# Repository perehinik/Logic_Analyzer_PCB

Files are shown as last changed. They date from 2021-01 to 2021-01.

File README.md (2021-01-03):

# Logic_Analizer_PCB
KiCad PCB project of Logic Analyzer

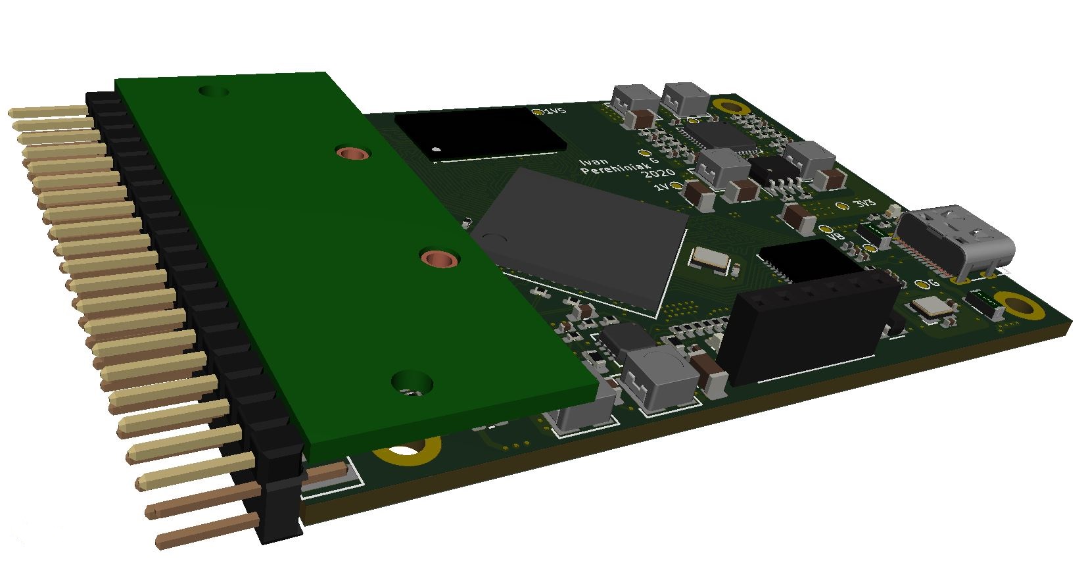
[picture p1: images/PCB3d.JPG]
  
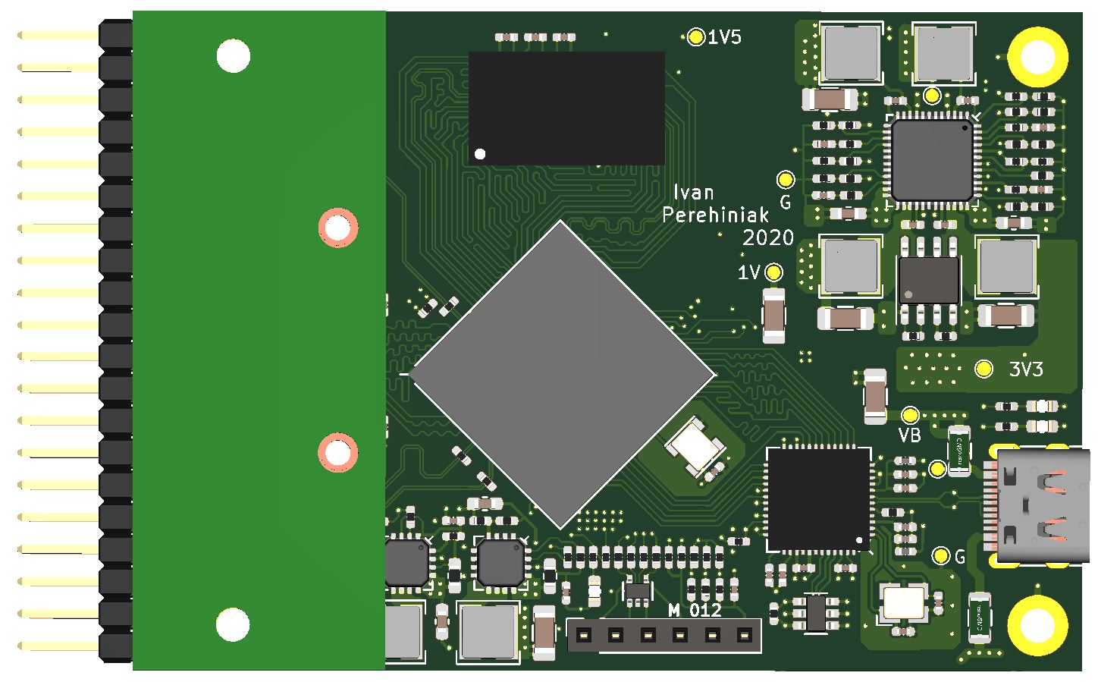
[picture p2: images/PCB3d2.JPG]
   
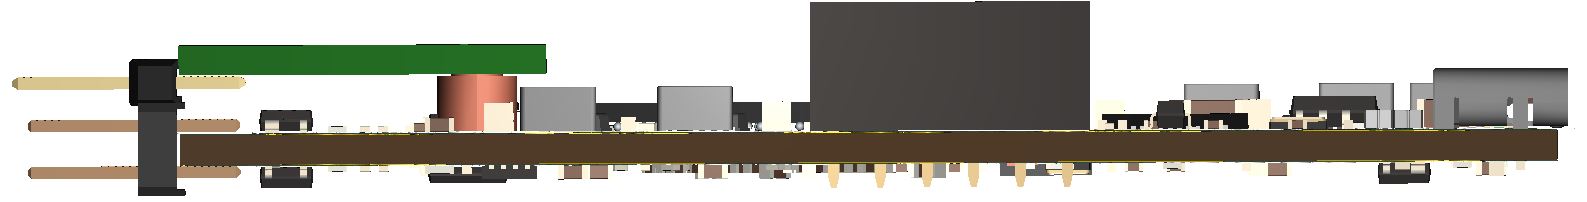
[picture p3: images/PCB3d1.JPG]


All components were soldered by hand using Zhaoxin 898DH station  
  
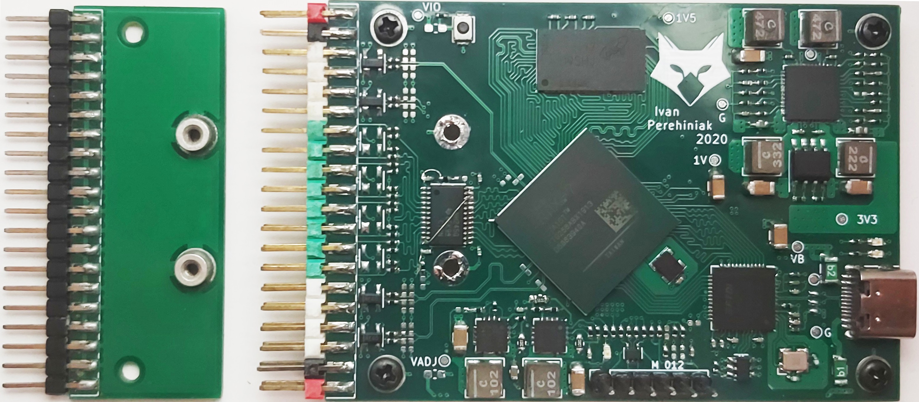
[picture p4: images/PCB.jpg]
   
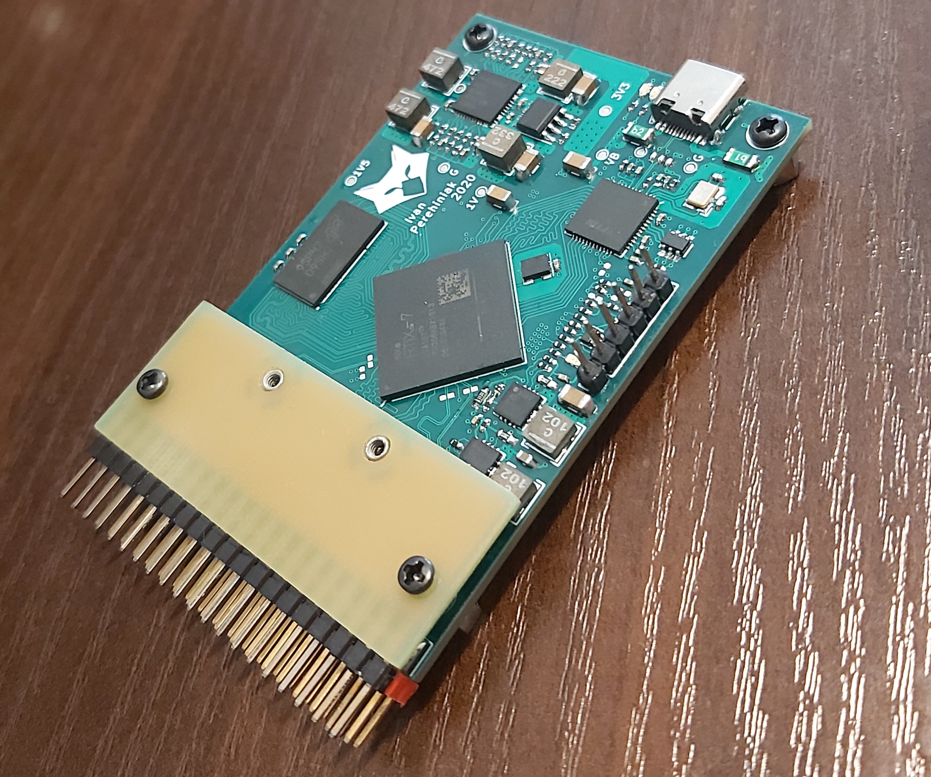
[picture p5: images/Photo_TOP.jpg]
   
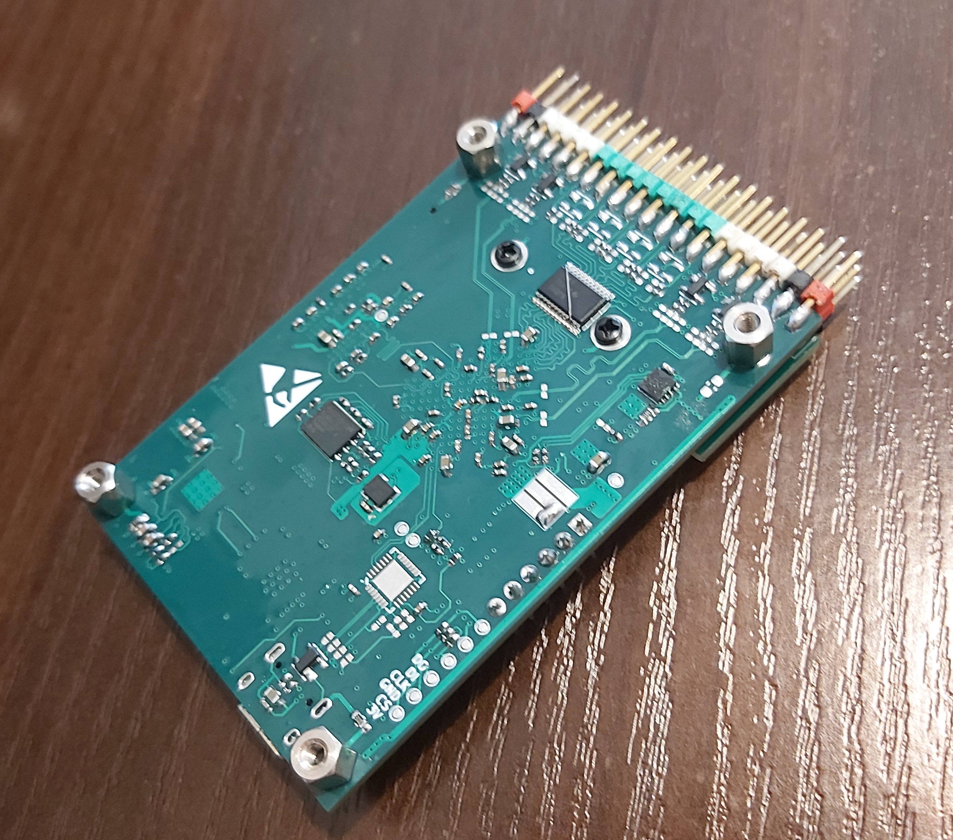
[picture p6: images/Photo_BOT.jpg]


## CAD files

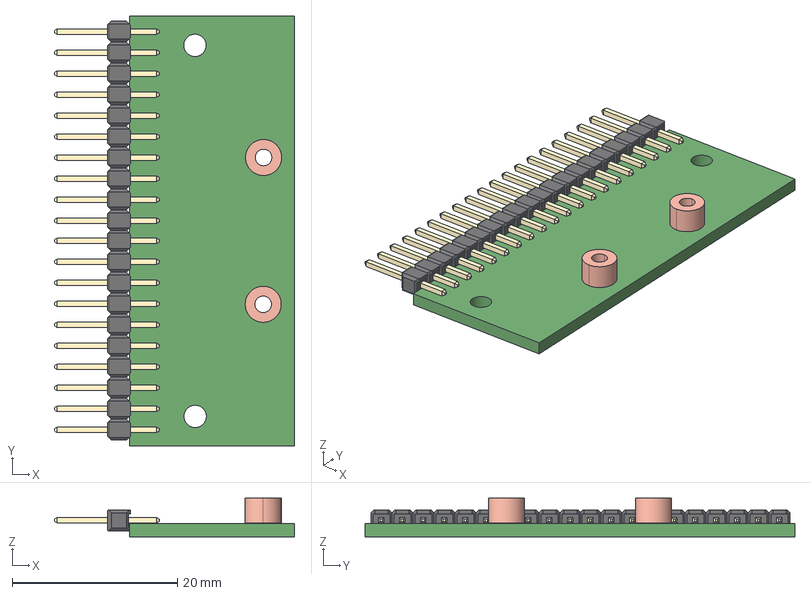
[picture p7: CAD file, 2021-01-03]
Project/GND_PCB/GND_PCB.step
29.1 x 52.0 x 4.70 mm

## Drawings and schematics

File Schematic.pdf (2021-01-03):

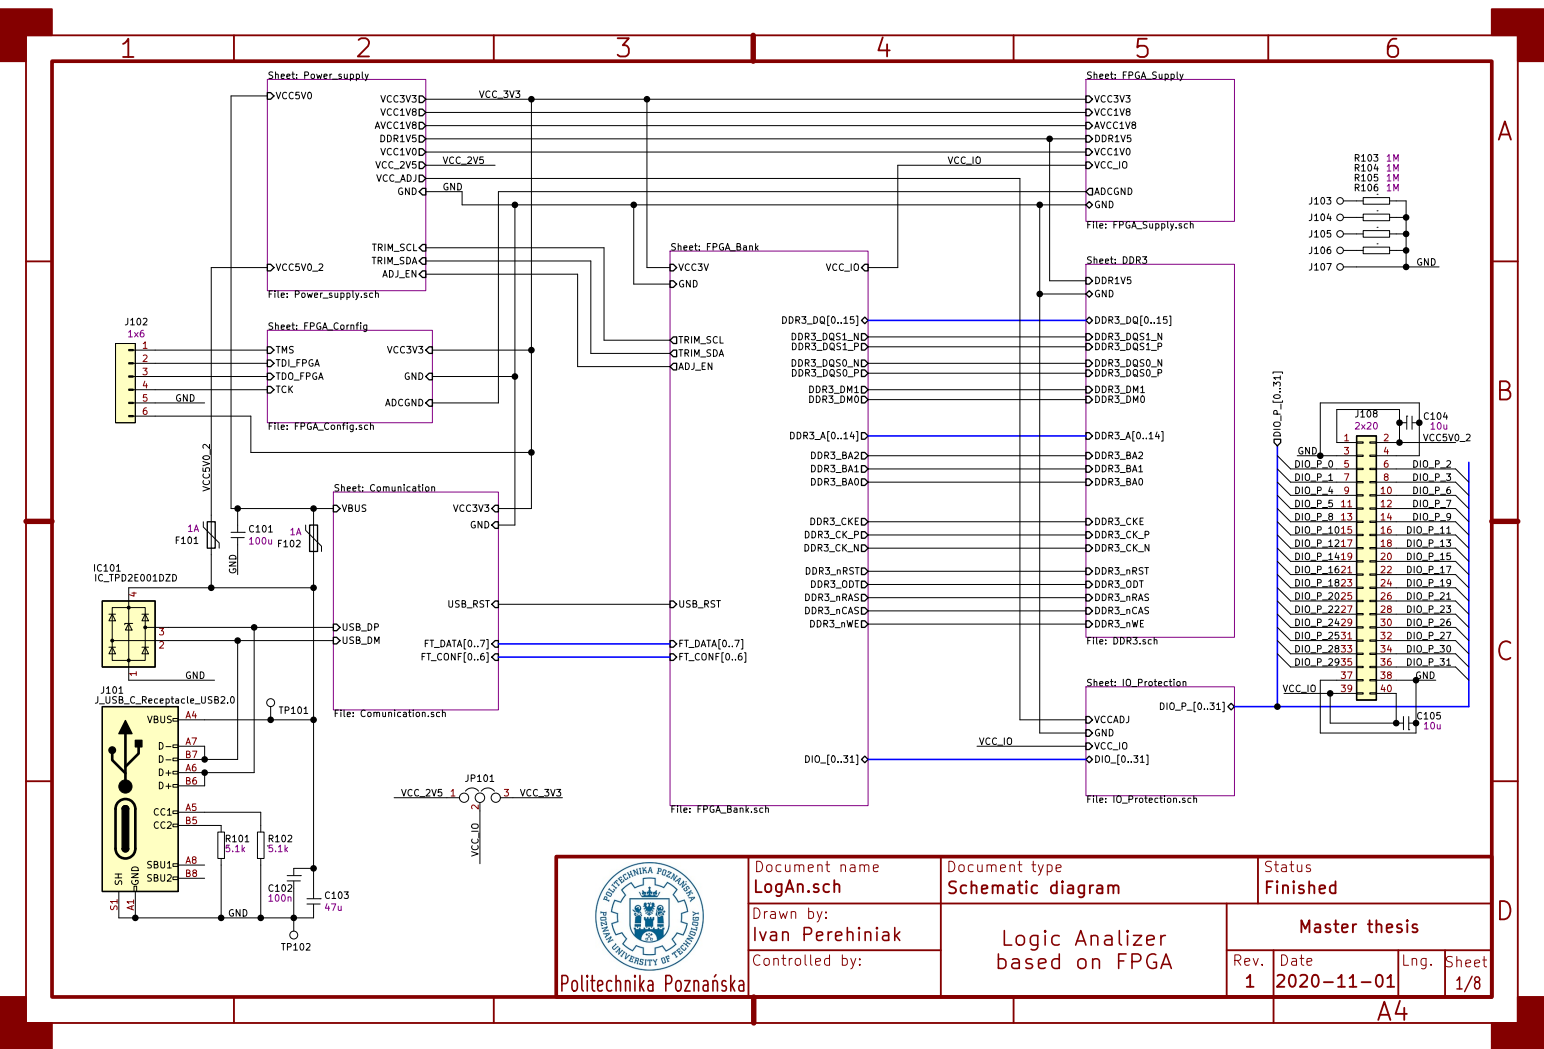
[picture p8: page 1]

Drawn by: Logic Analizer

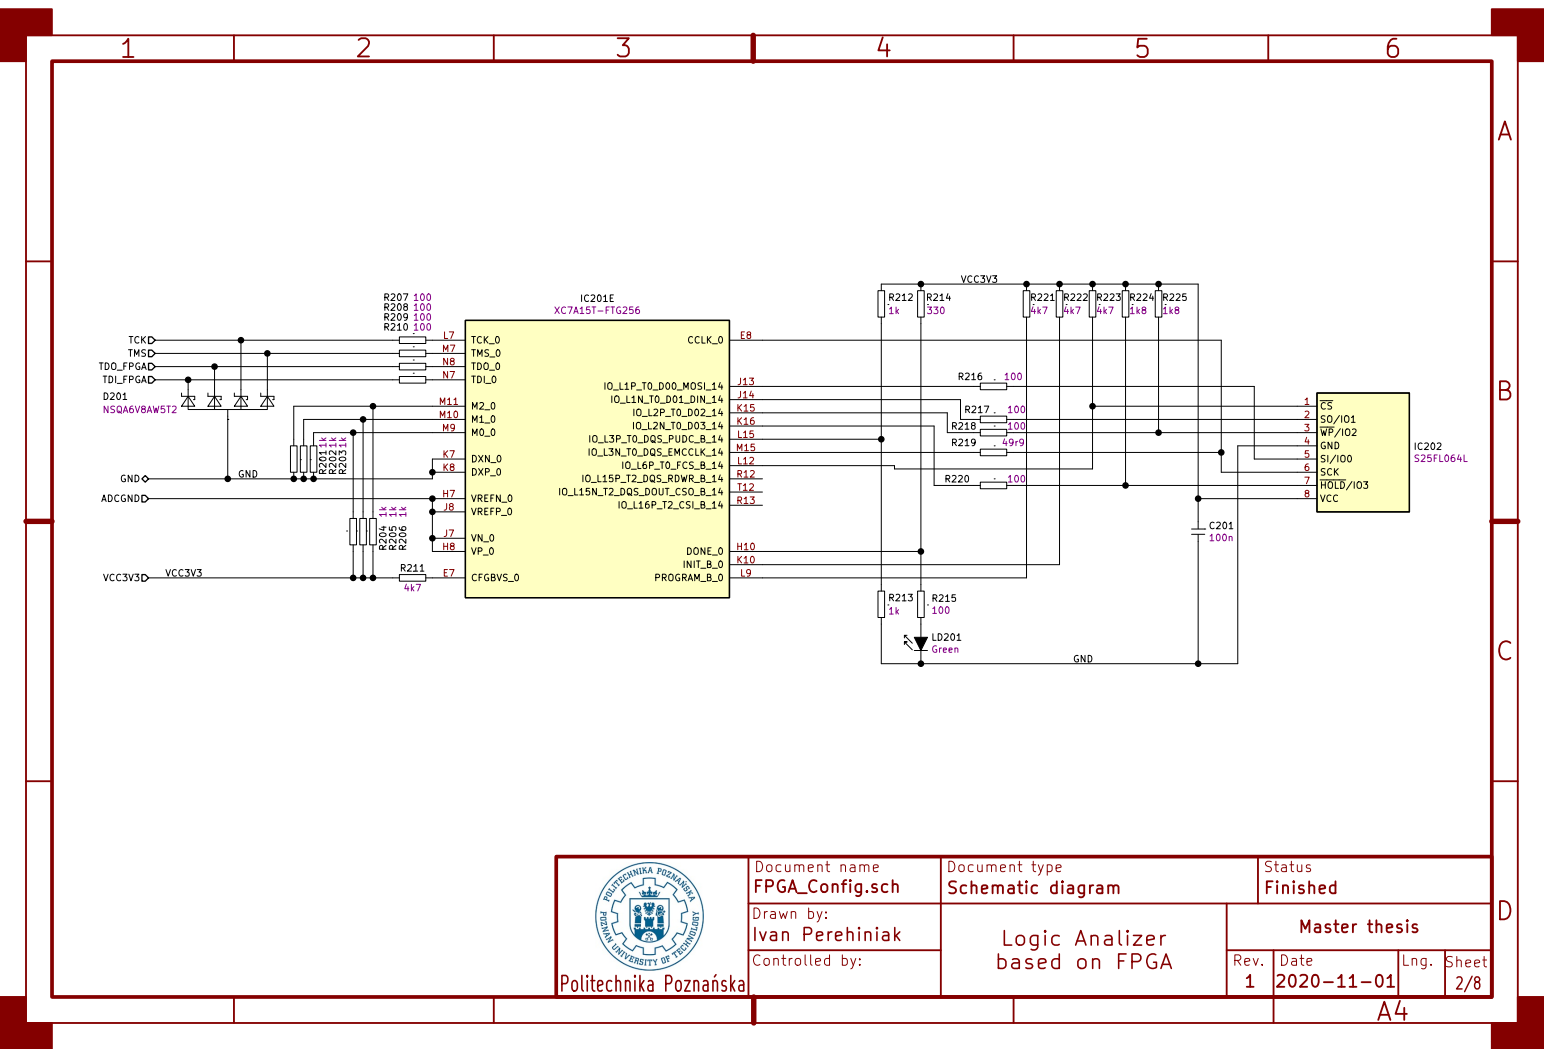
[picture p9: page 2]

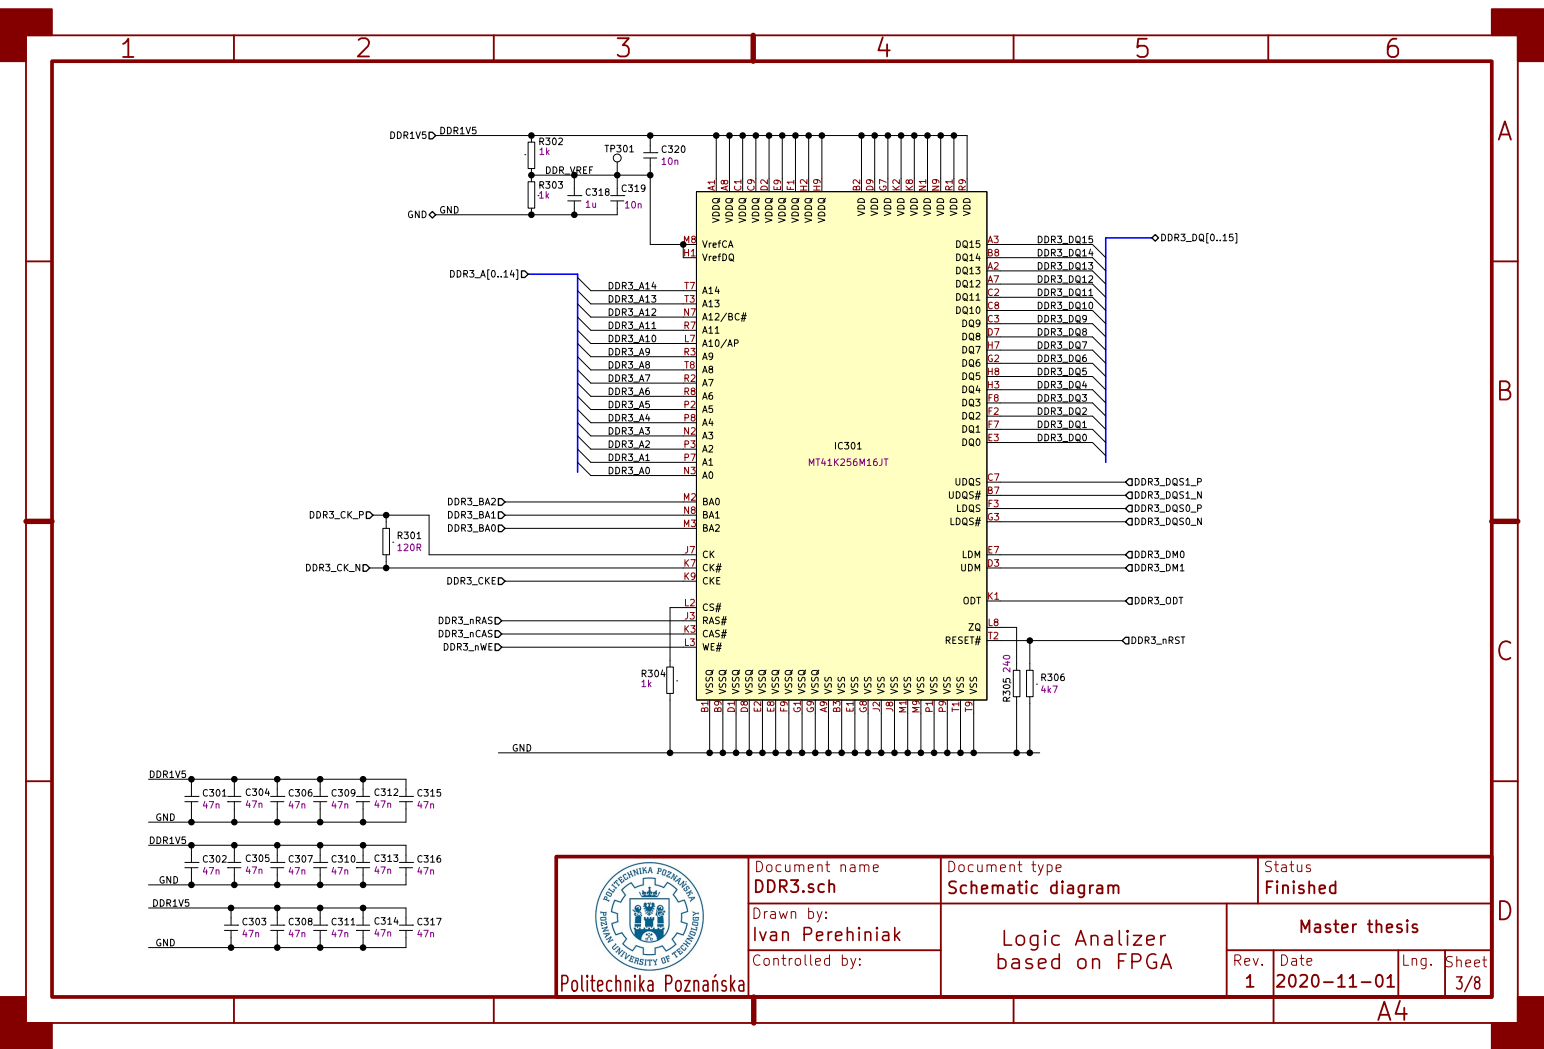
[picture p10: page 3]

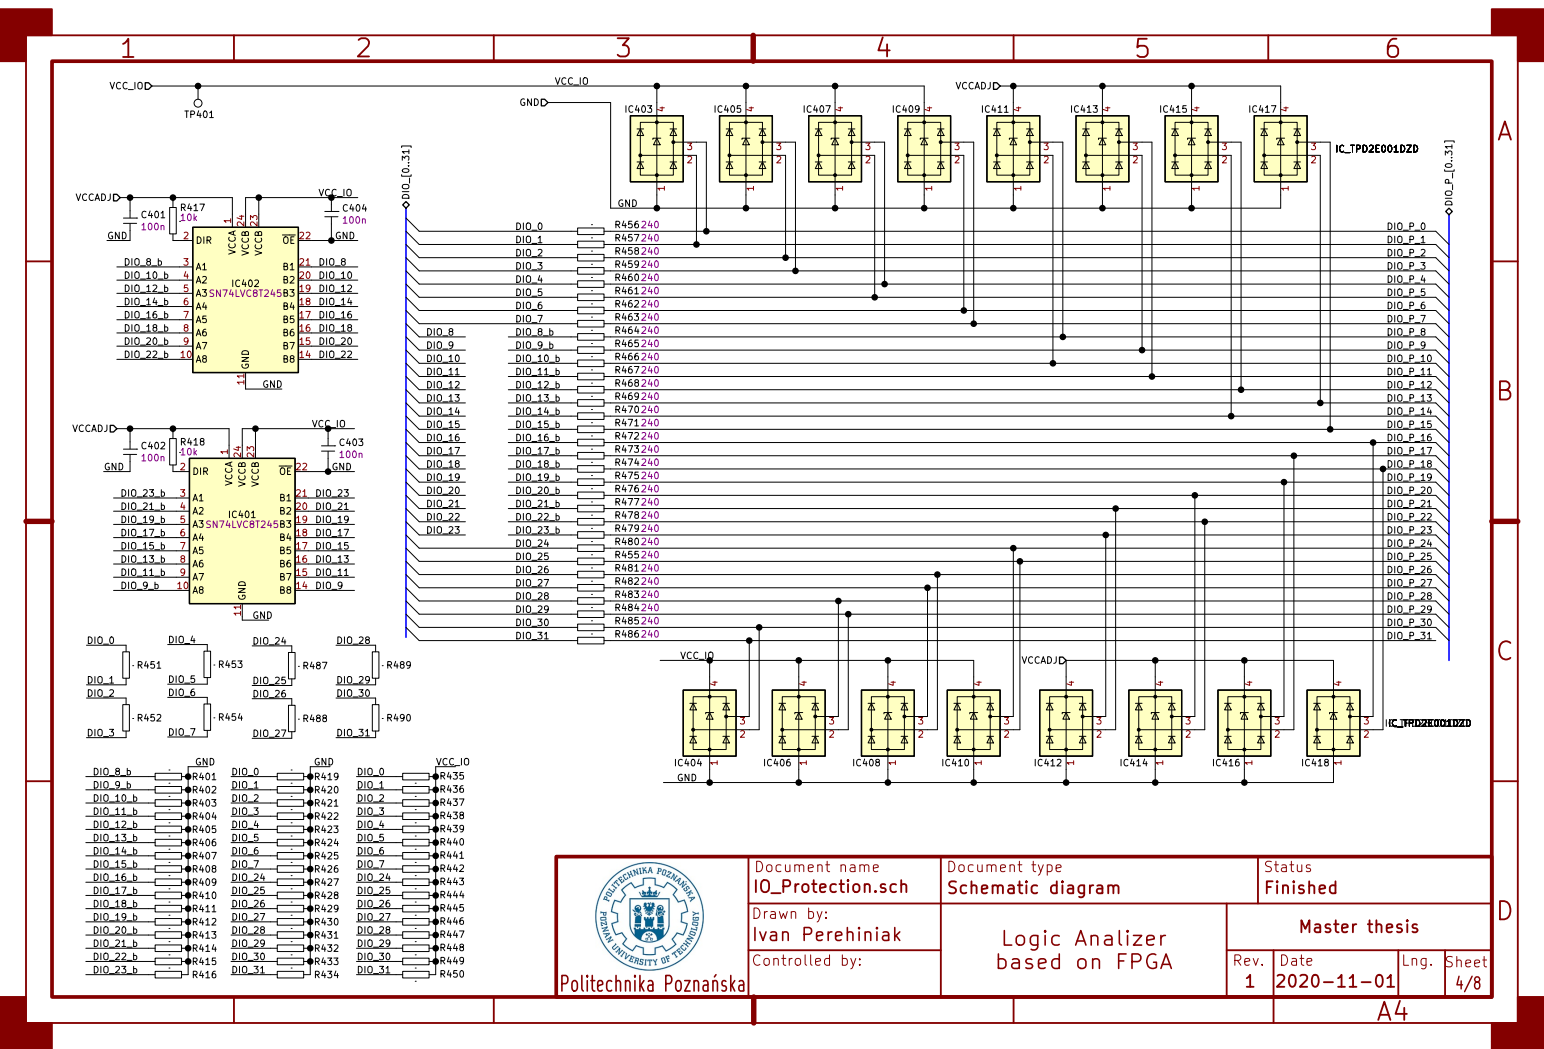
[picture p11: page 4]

1 A8 10 GND 11 B8 14 B7 15 B6 16 B5 17 B4 18 B3 19 DIR 2 B2 20 B1 21 OE 22 VCCB 23 VCCB 24 A1 3 A2 4 A3 5 A4 6 A5 7 A6 8 A7 9

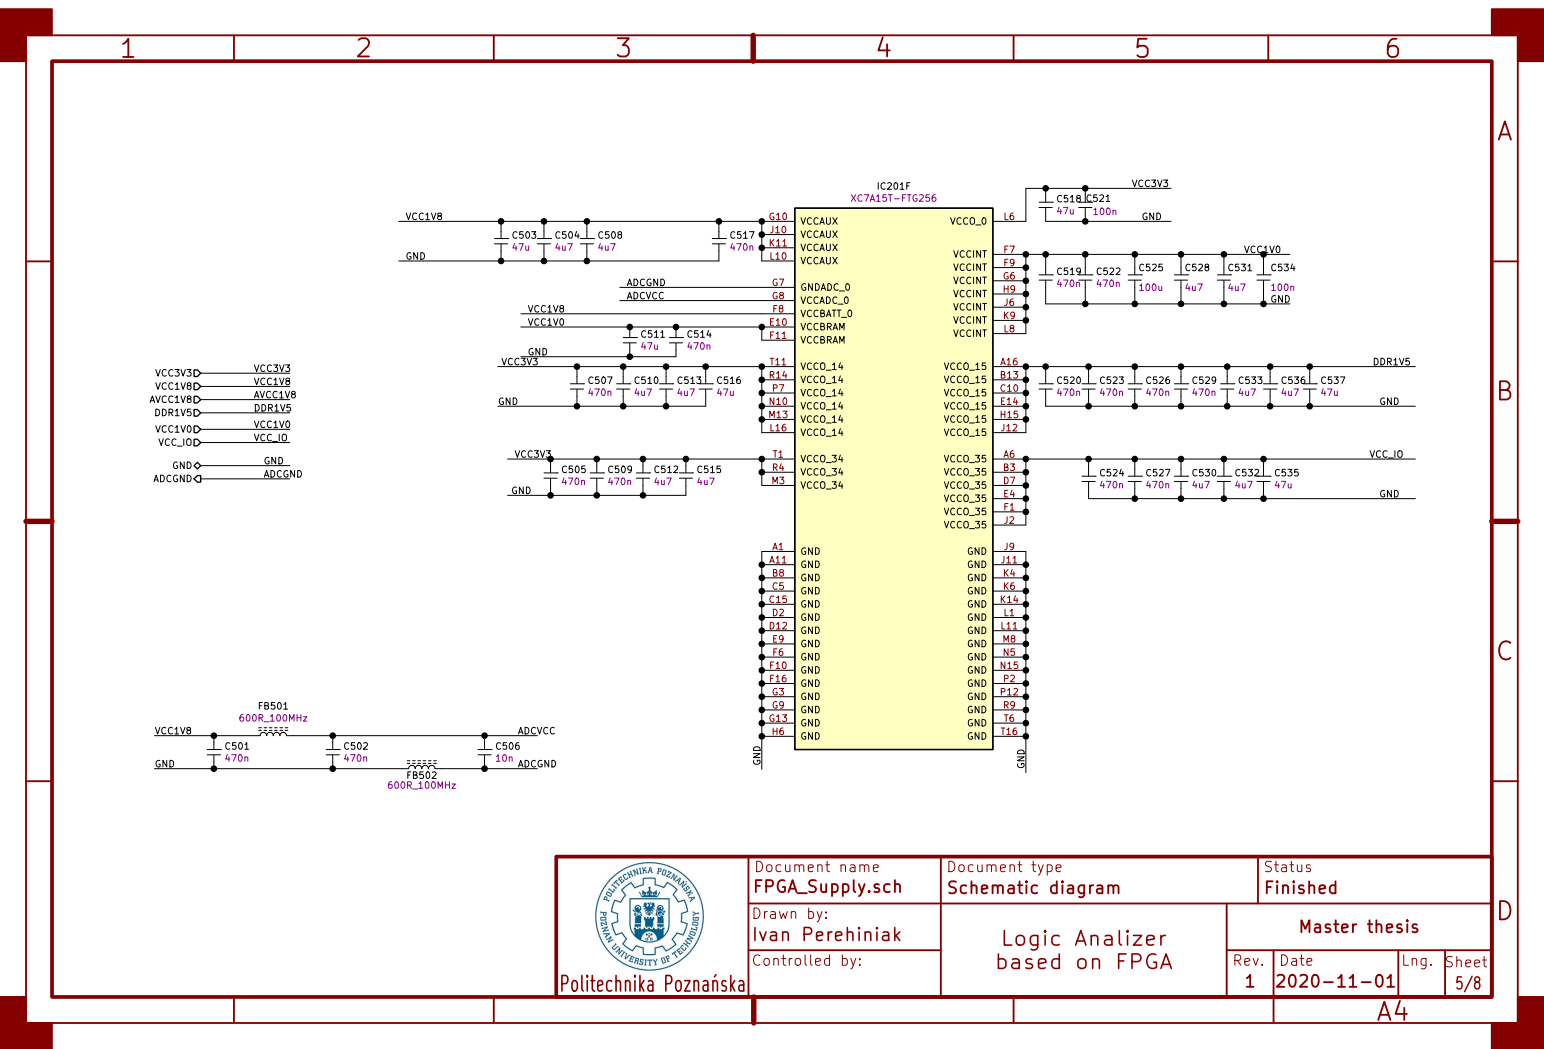
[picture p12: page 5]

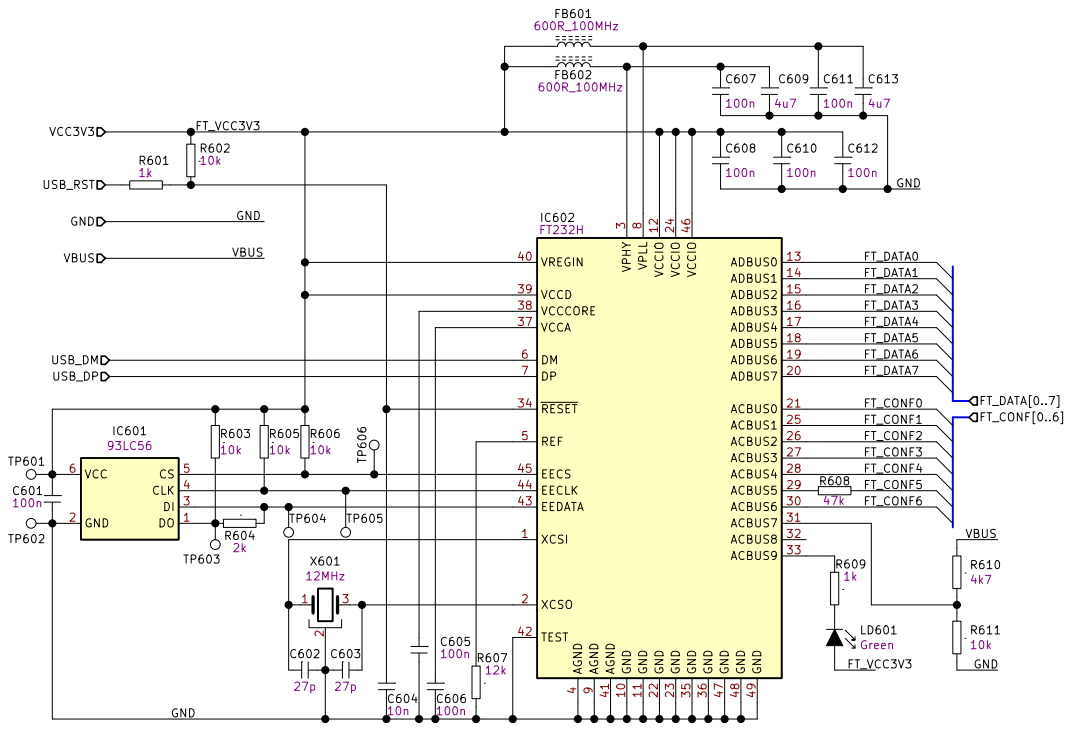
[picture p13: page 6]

4 VREGIN 40 AGND 41 TEST 42 EEDATA 43 EECLK 44 EECS 45 VCCIO 46 GND 47 GND 48 GND 49 REF 5 DM 6 DP 7 VPLL

3 ACBUS6 30 ACBUS7 31 ACBUS8 32 ACBUS9 33 RESET 34 GND 35 GND 36 VCCA 37 VCCCORE 38 VCCD 39 AGND

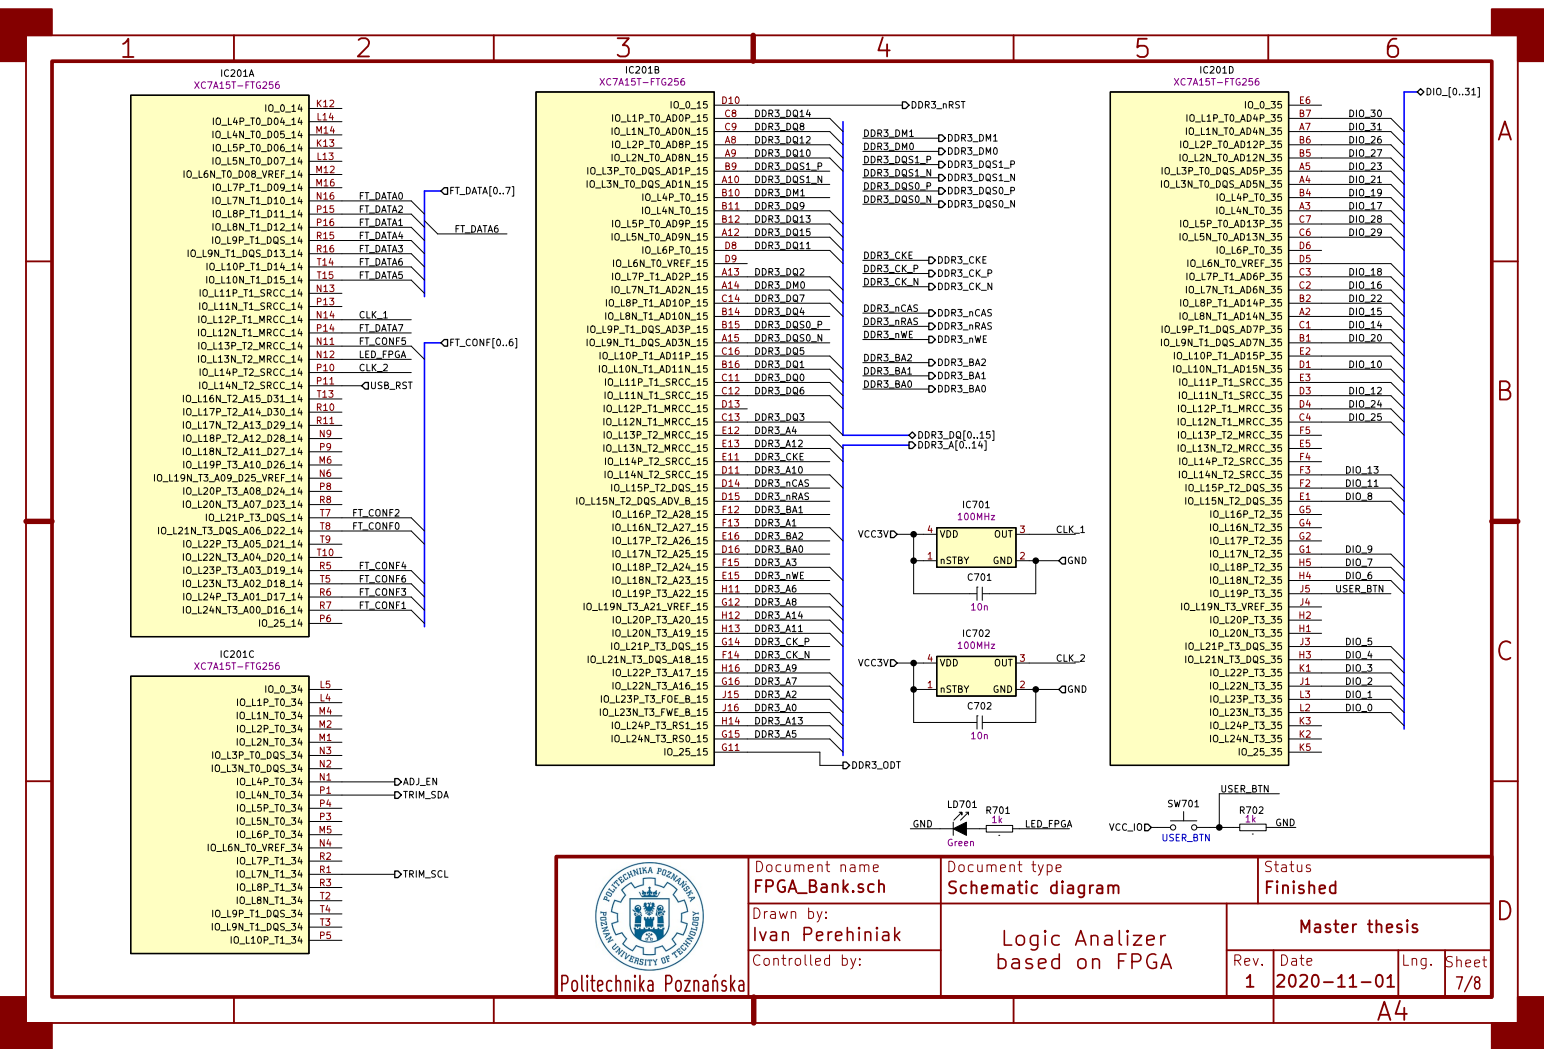
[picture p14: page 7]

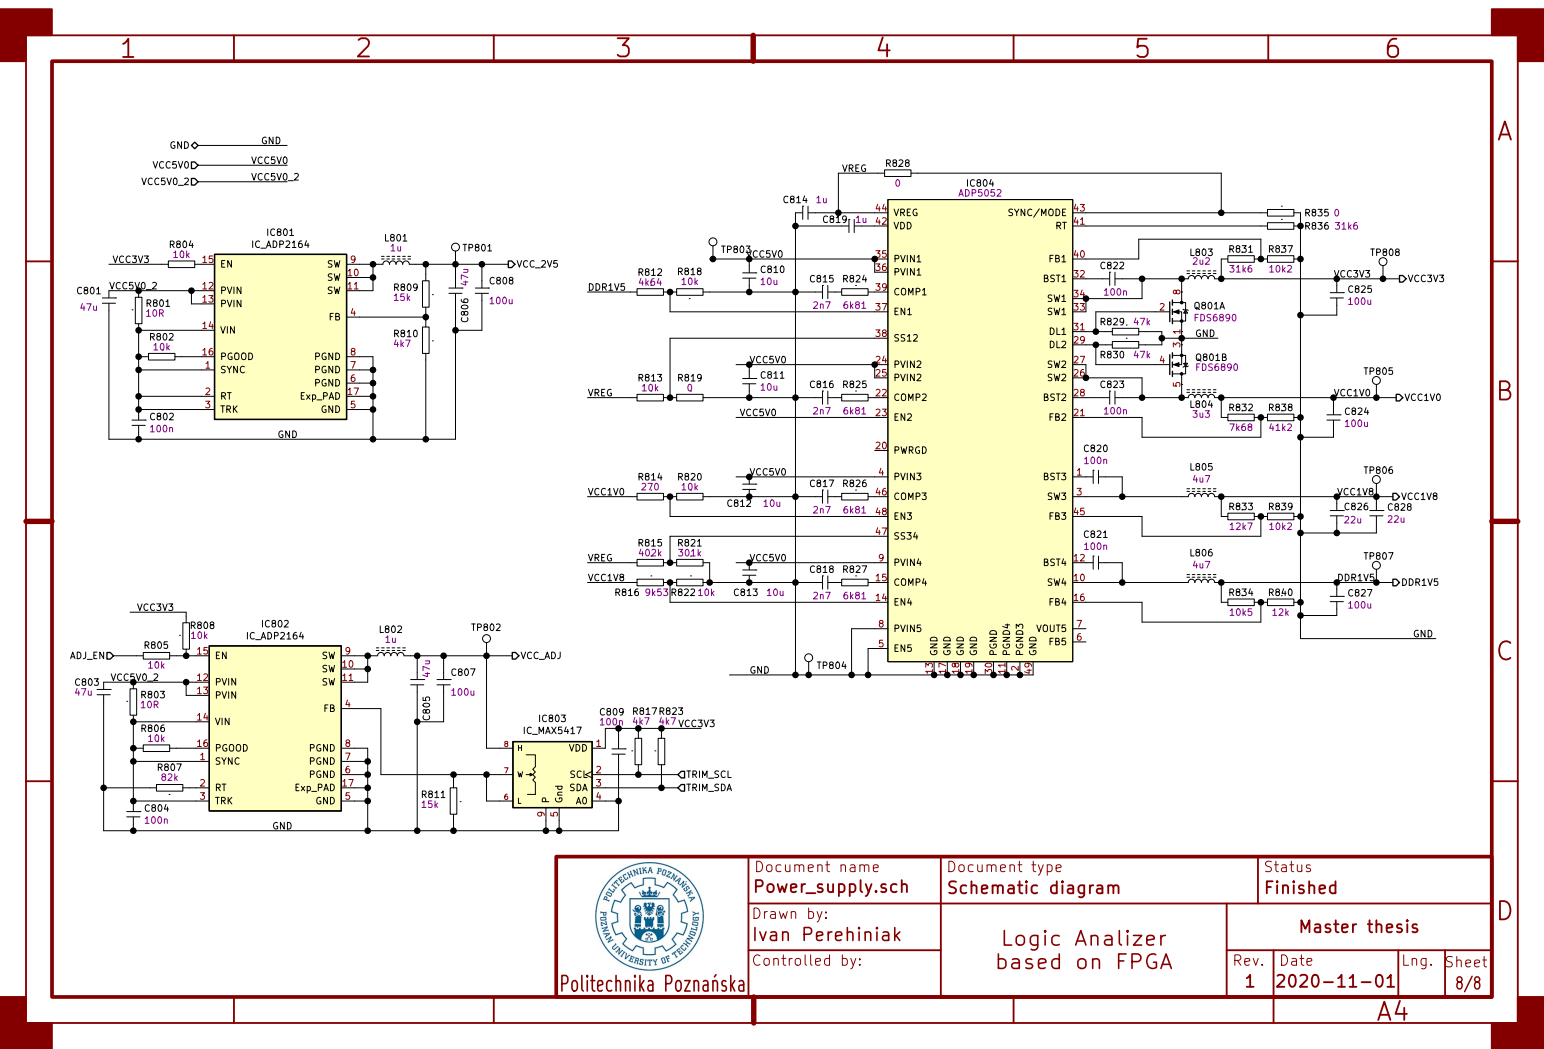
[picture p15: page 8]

2 PWRGD 20 FB2 21 COMP2 22 EN2 23 PVIN2 24 PVIN2 25 SW2 26 SW2 27 BST2 28 DL2 29 SW3 3 PGND 30 DL1 31 BST1 32 SW1 33 SW1 34 PVIN1 35 PVIN1 36 EN1 37 SS12 38 COMP1 39 PVIN3 4 FB1 40 RT 41 VDD 42 SYNC/MODE 43 VREG 44 FB3 45 COMP3 46 SS34 47 EN3 48 GND 49 EN5 5 FB5 6 VOUT5 7 PVIN5 8 PVIN4 9

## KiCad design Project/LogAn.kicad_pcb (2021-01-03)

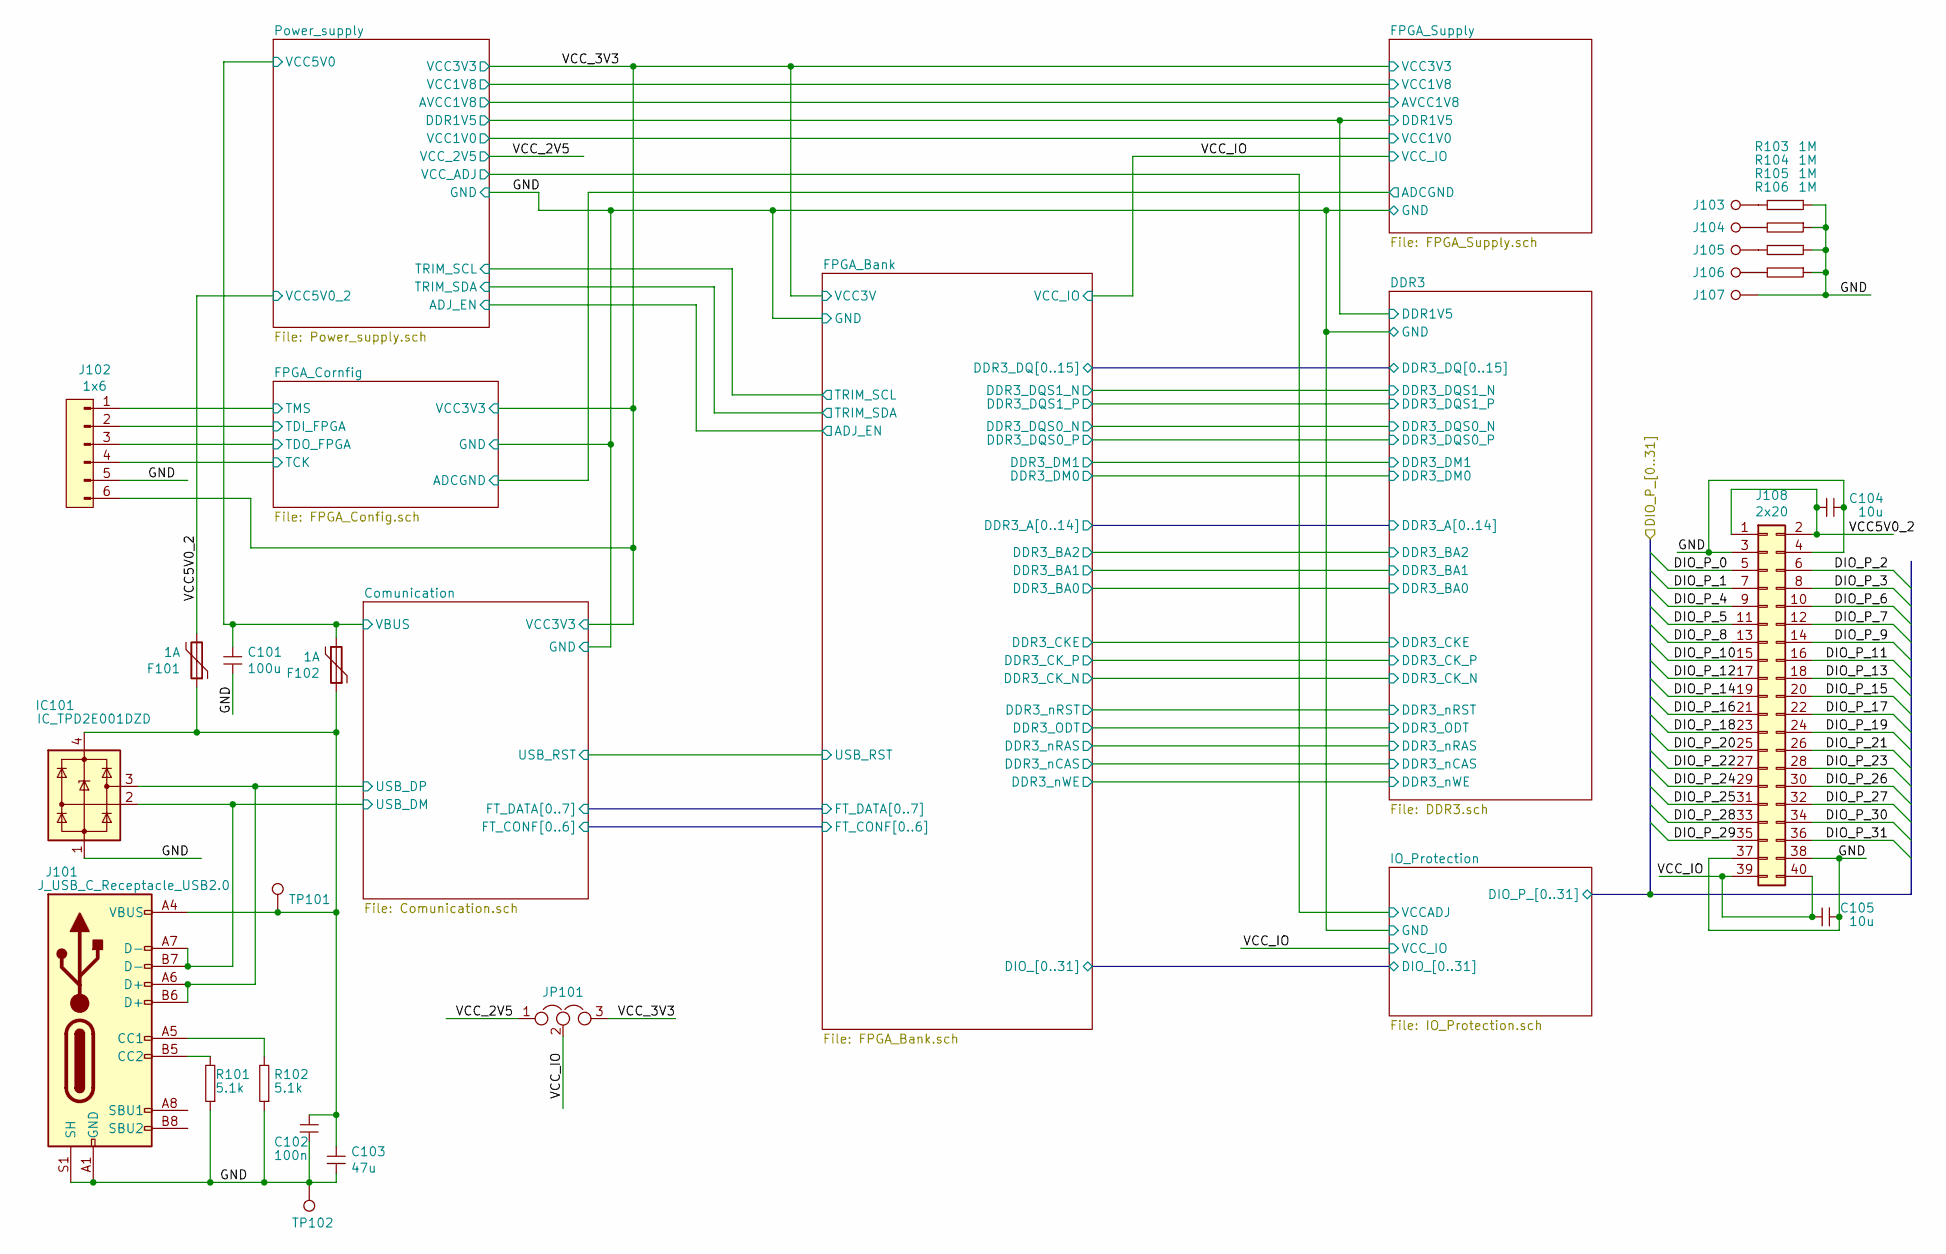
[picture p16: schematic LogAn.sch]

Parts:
C101: C_100u_1206_6V3; C_1206_3216Metric_Pad1.42x1.75mm_HandSolder
C102: C_100n_0402_16V; C_0402_1005Metric
C103: C_47u_0603_6V3; C_0603_1608Metric_Pad1.05x0.95mm_HandSolder
C104, C105: C_10u_0603_10V; C_0603_1608Metric_Pad1.05x0.95mm_HandSolder
F101, F102: F_Polyfuse_1A_1206; Fuse_1206_3216Metric
IC101: IC_TPD2E001DZD; SOT-143(R_PDSO-G4)
J101: J_USB_C_Receptacle_USB2.0; USB_C_Receptacle_HRO_TYPE-C-31-M-12
J102: J_Conn_01x06_Male_2_54; PinSocket_1x06_P2.54mm_Vertical
J103, J104, J105, J106: MH_M2_5; MH_2_5_mm
J107: GND_PCB
J108: J_Conn_02x20_2.5_M_SMD_HOR; PinSocket_2x20_P2.54mm_SMD_HOR
JP101: Jumper_NC_Dual; SolderJumper_6_2
R101, R102: R_5k1_0402_1%; R_0402_1005Metric
R103, R104, R105, R106: R_1M_0603_5%; R_0603_1608Metric_Pad1.05x0.95mm_HandSolder
TP101, TP102: TestPoint; TestPoint_Pad_D1.0mm

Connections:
/Comunication/USB_DM: IC101.2, J101.A7 (D-), J101.B7 (D-); also elsewhere on the board
/Comunication/USB_DP: IC101.3, J101.A6 (D+), J101.B6 (D+); also elsewhere on the board
/Comunication/VBUS: C101.1, F102.2; also elsewhere on the board
/DIO_P_0: J108.5; also elsewhere on the board
/DIO_P_1: J108.7; also elsewhere on the board
/DIO_P_2: J108.6; also elsewhere on the board
/DIO_P_3: J108.8; also elsewhere on the board
/DIO_P_4: J108.9; also elsewhere on the board
/DIO_P_5: J108.11; also elsewhere on the board
/DIO_P_6: J108.10; also elsewhere on the board
/DIO_P_7: J108.12; also elsewhere on the board
/DIO_P_8: J108.13; also elsewhere on the board
/DIO_P_9: J108.14; also elsewhere on the board
/DIO_P_10: J108.15; also elsewhere on the board
/DIO_P_11: J108.16; also elsewhere on the board
/DIO_P_12: J108.17; also elsewhere on the board
/DIO_P_13: J108.18; also elsewhere on the board
/DIO_P_14: J108.19; also elsewhere on the board
/DIO_P_15: J108.20; also elsewhere on the board
/DIO_P_16: J108.21; also elsewhere on the board
/DIO_P_17: J108.22; also elsewhere on the board
/DIO_P_18: J108.23; also elsewhere on the board
/DIO_P_19: J108.24; also elsewhere on the board
/DIO_P_20: J108.25; also elsewhere on the board
/DIO_P_21: J108.26; also elsewhere on the board
/DIO_P_22: J108.27; also elsewhere on the board
/DIO_P_23: J108.28; also elsewhere on the board
/DIO_P_24: J108.29; also elsewhere on the board
/DIO_P_25: J108.31; also elsewhere on the board
/DIO_P_26: J108.30; also elsewhere on the board
/DIO_P_27: J108.32; also elsewhere on the board
/DIO_P_28: J108.33; also elsewhere on the board
/DIO_P_29: J108.35; also elsewhere on the board
/DIO_P_30: J108.34; also elsewhere on the board
/DIO_P_31: J108.36; also elsewhere on the board
/FPGA_Cornfig/TCK: J102.4; also elsewhere on the board
/FPGA_Cornfig/TDI_FPGA: J102.2; also elsewhere on the board
/FPGA_Cornfig/TDO_FPGA: J102.3; also elsewhere on the board
/FPGA_Cornfig/TMS: J102.1; also elsewhere on the board
/GND: C101.2, C102.2, C103.2, C104.2, C105.1, IC101.1, J101.A1 (GND), J101.A12 (GND), J101.B1 (GND), J101.B12 (GND), J101.S1 (SH), J102.5, J107.1, J108.3, J108.4, J108.37, J108.38, R101.2, R102.2, R103.2, R104.2, R105.2, R106.2, TP102.1; also elsewhere on the board
/VCC5V0_2: C104.1, F101.2, J108.1, J108.2; also elsewhere on the board
/VCC_2V5: JP101.1; also elsewhere on the board
/VCC_IO: C105.2, J108.39, J108.40, JP101.2; also elsewhere on the board
unnamed: C102.1, C103.1, F101.1, F102.1, IC101.4, J101.A4 (VBUS), J101.A9 (VBUS), J101.B4 (VBUS), J101.B9 (VBUS), TP101.1
unnamed: J101.A5 (CC1), R102.1
unnamed: J101.B5 (CC2), R101.1
unnamed: J103.1, R103.1
unnamed: J104.1, R104.1
unnamed: J105.1, R105.1
unnamed: J106.1, R106.1

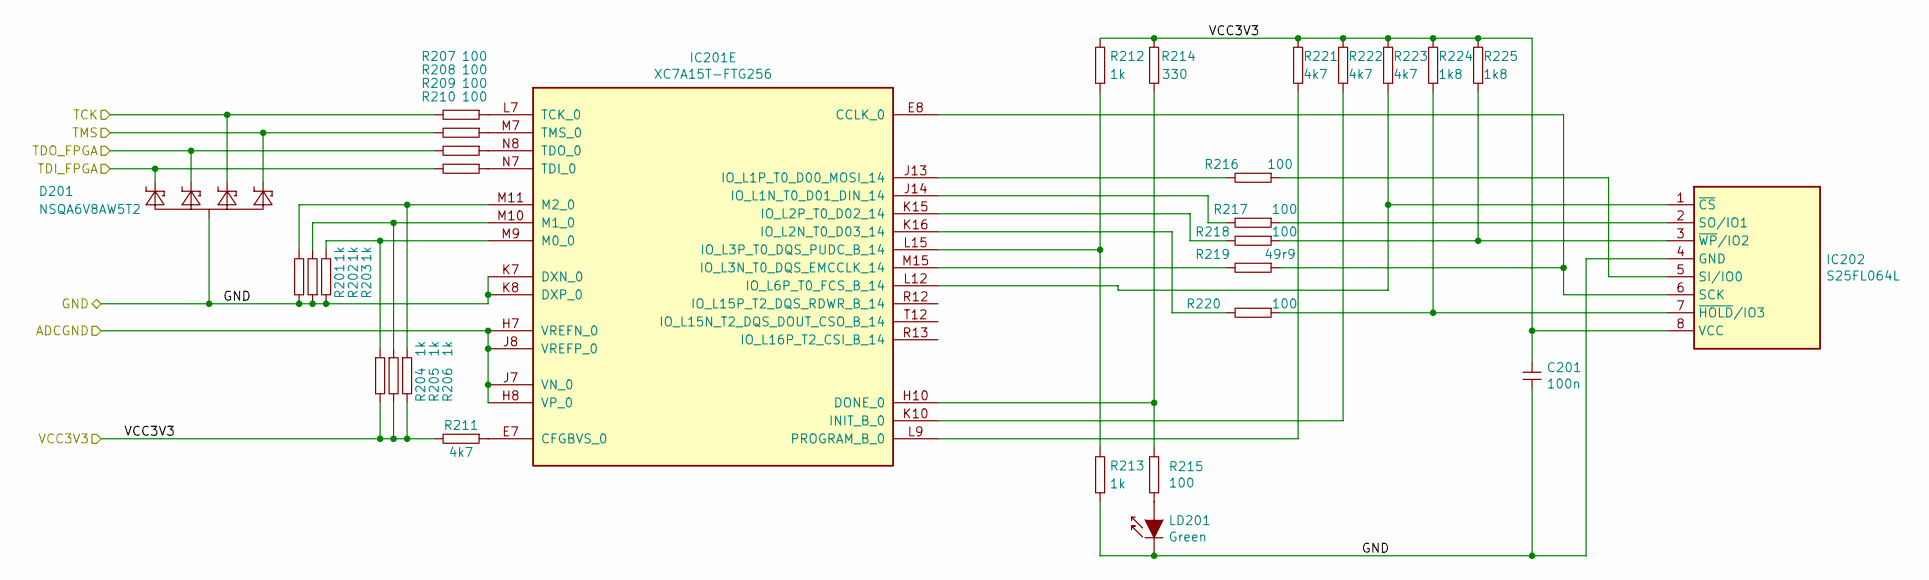
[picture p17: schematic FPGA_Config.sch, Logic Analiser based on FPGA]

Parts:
C201: C_100n_0402_16V; C_0402_1005Metric
D201: D_NSQA6V8AW5T2_SOT23; SOT-353_SC-70-5
IC201: IC_XC7A15T_FTG256; Xilinx_FTG256
IC202: IC_S25FL064L-ABNFI040_WSON8; WSON-8-1EP_6x5mm_P1.27mm_EP3.4x4mmj
LD201: LED_Green_0603; LED_0603_1608Metric
R201, R202, R203, R204, R205, R206, R212, R213: R_1k_0402_5%; R_0402_1005Metric
R207, R208, R209, R210, R215, R216, R217, R218, R220: R_100r_0402_5%; R_0402_1005Metric
R211, R221, R222, R223: R_4k7_0402_5%; R_0402_1005Metric
R214: R_330r_0402_5%; R_0402_1005Metric
R219: R_49r9_0402_1%; R_0402_1005Metric
R224, R225: R_1k8_0402_5%; R_0402_1005Metric

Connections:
/FPGA_Cornfig/ADCGND: IC201.H7 (VREFN_0), IC201.H8 (VP_0), IC201.J7 (VN_0), IC201.J8 (VREFP_0); also elsewhere on the board
/FPGA_Cornfig/TCK: D201.4, R207.1; also elsewhere on the board
/FPGA_Cornfig/TDI_FPGA: D201.1, R210.1; also elsewhere on the board
/FPGA_Cornfig/TDO_FPGA: D201.3, R209.1; also elsewhere on the board
/FPGA_Cornfig/TMS: D201.5, R208.1; also elsewhere on the board
/GND: C201.2, D201.2, IC201.K7 (DXN_0), IC201.K8 (DXP_0), IC202.4 (GND), IC202.9 (GND), LD201.1 (K), R201.2, R202.2, R203.2, R213.2; also elsewhere on the board
unnamed: IC201.E7 (CFGBVS_0), R211.2
unnamed: IC201.E8 (CCLK_0), IC202.6 (SCK), R219.2
unnamed: IC201.H10 (DONE_0), R214.2, R215.1
unnamed: IC201.J13 (IO_L1P_T0_D00_MOSI_14), R216.1
unnamed: IC201.J14 (IO_L1N_T0_D01_DIN_14), R217.1
unnamed: IC201.K10 (INIT_B_0), R222.2
unnamed: IC201.K15 (IO_L2P_T0_D02_14), R218.1
unnamed: IC201.K16 (IO_L2N_T0_D03_14), R220.1
unnamed: IC201.L7 (TCK_0), R207.2
unnamed: IC201.L9 (PROGRAM_B_0), R221.2
unnamed: IC201.L12 (IO_L6P_T0_FCS_B_14), IC202.1 (~CS), R223.2
unnamed: IC201.L15 (IO_L3P_T0_DQS_PUDC_B_14), R212.2, R213.1
unnamed: IC201.M7 (TMS_0), R208.2
unnamed: IC201.M9 (M0_0), R203.1, R204.2
unnamed: IC201.M10 (M1_0), R202.1, R205.2
unnamed: IC201.M11 (M2_0), R201.1, R206.2
unnamed: IC201.M15 (IO_L3N_T0_DQS_EMCCLK_14), R219.1
unnamed: IC201.N7 (TDI_0), R210.2
unnamed: IC201.N8 (TDO_0), R209.2
unnamed: IC202.2 (SO/IO1), R217.2
unnamed: IC202.3 (~WP~/IO2), R218.2, R225.2
unnamed: IC202.5 (SI/IO0), R216.2
unnamed: IC202.7 (~HOLD~/IO3), R220.2, R224.2
unnamed: LD201.2 (A), R215.2

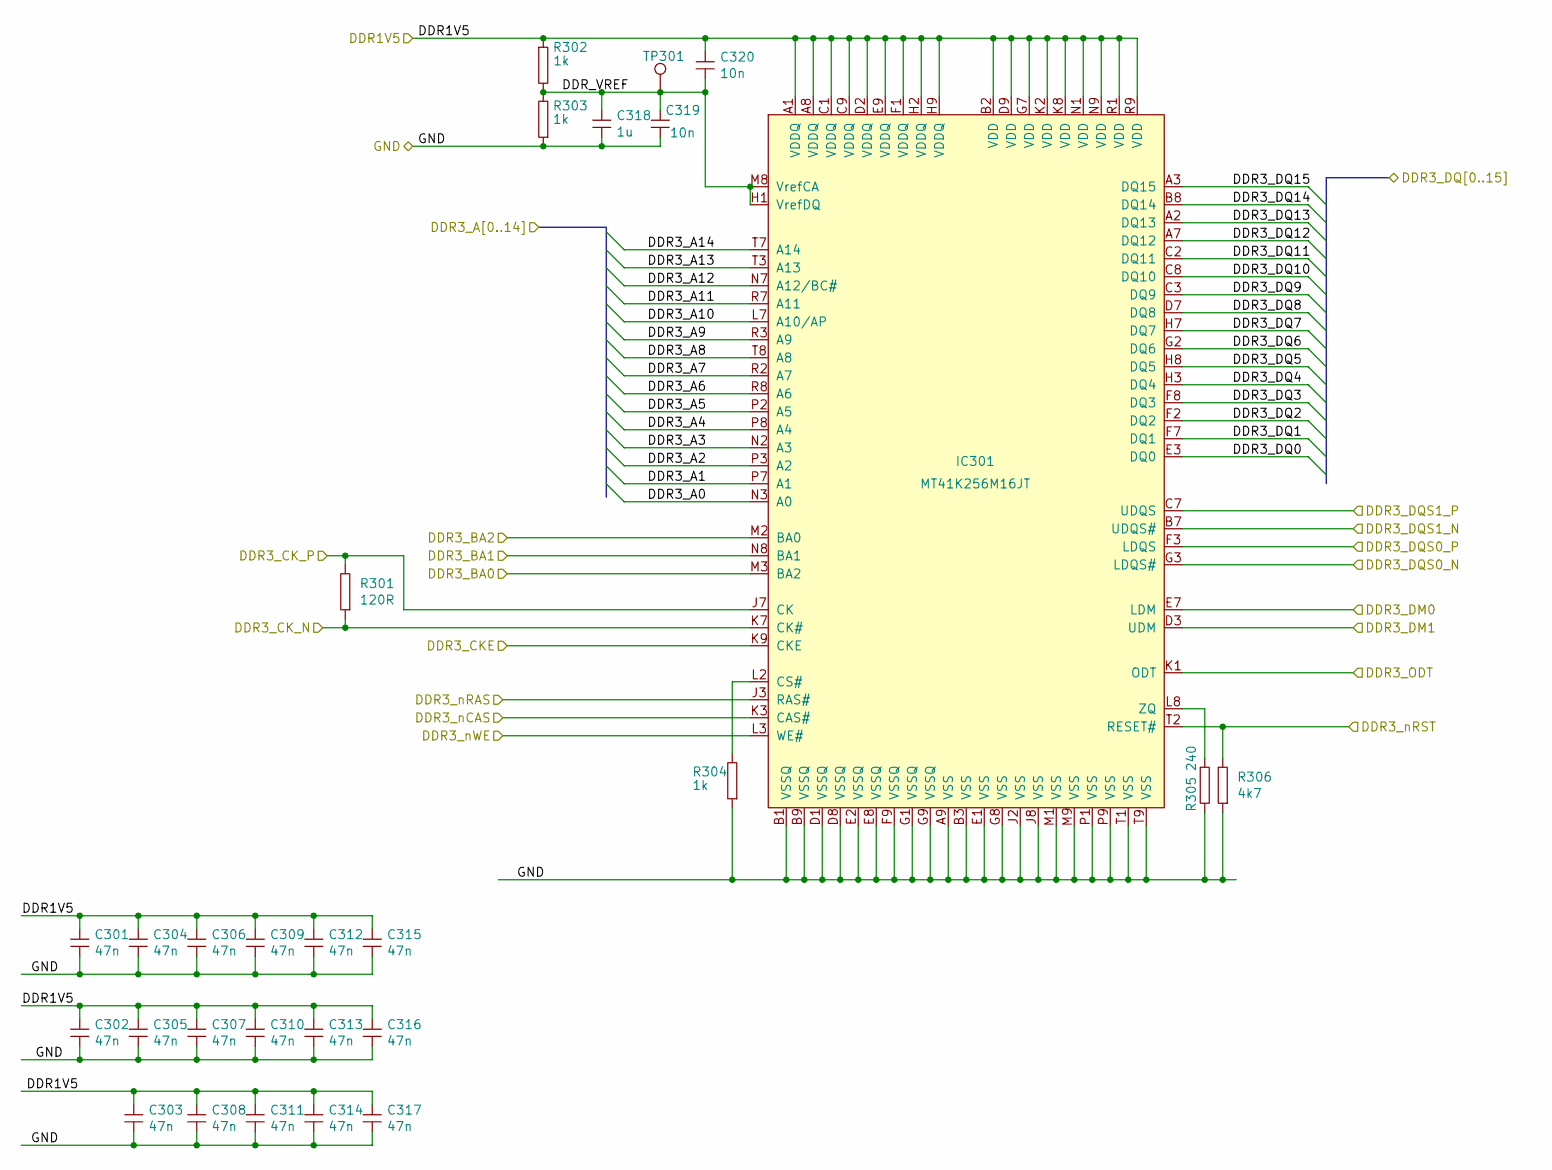
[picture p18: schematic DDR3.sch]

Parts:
C301, C302, C303, C304, C305, C306, C307, C308, C309, C310, C311, C312, C313, C314, C315, C316, C317: C_47n_0402_16V; C_0402_1005Metric
C318: C_1u_0603_10V; C_0603_1608Metric_Pad1.05x0.95mm_HandSolder
C319, C320: C_10n_0402_16V; C_0402_1005Metric
IC301: IC_MT41K128M16JT-125K_FBGA96; FBGA96_C80P9X16_800X1400X120
R301: R_80r6_0402_1%; R_0402_1005Metric
R302, R303: R_1k_0402_1%; R_0402_1005Metric
R304: R_1k_0402_5%; R_0402_1005Metric
R305: R_240r_0402_1%; R_0402_1005Metric
R306: R_4k7_0402_5%; R_0402_1005Metric
TP301: TestPoint; TestPoint_Pad_D1.0mm

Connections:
/DDR3/DDR1V5: C301.1, C302.1, C303.1, C304.2, C305.2, C306.1, C307.1, C308.1, C309.1, C310.1, C311.1, C312.2, C313.2, C314.2, C315.1, C316.1, C317.1, C320.1, IC301.A1 (VDDQ), IC301.A8 (VDDQ), IC301.B2 (VDD), IC301.C1 (VDDQ), IC301.C9 (VDDQ), IC301.D2 (VDDQ), IC301.D9 (VDD), IC301.E9 (VDDQ), IC301.F1 (VDDQ), IC301.G7 (VDD), IC301.H2 (VDDQ), IC301.H9 (VDDQ), IC301.K2 (VDD), IC301.K8 (VDD), IC301.N1 (VDD), IC301.N9 (VDD), IC301.R1 (VDD), IC301.R9 (VDD), R302.2; also elsewhere on the board
/DDR3/DDR3_A0: IC301.N3 (A0); also elsewhere on the board
/DDR3/DDR3_A1: IC301.P7 (A1); also elsewhere on the board
/DDR3/DDR3_A2: IC301.P3 (A2); also elsewhere on the board
/DDR3/DDR3_A3: IC301.N2 (A3); also elsewhere on the board
/DDR3/DDR3_A4: IC301.P8 (A4); also elsewhere on the board
/DDR3/DDR3_A5: IC301.P2 (A5); also elsewhere on the board
/DDR3/DDR3_A6: IC301.R8 (A6); also elsewhere on the board
/DDR3/DDR3_A7: IC301.R2 (A7); also elsewhere on the board
/DDR3/DDR3_A8: IC301.T8 (A8); also elsewhere on the board
/DDR3/DDR3_A9: IC301.R3 (A9); also elsewhere on the board
/DDR3/DDR3_A10: IC301.L7 (A10/AP); also elsewhere on the board
/DDR3/DDR3_A11: IC301.R7 (A11); also elsewhere on the board
/DDR3/DDR3_A12: IC301.N7 (A12/BC#); also elsewhere on the board
/DDR3/DDR3_A13: IC301.T3 (A13); also elsewhere on the board
/DDR3/DDR3_A14: IC301.T7 (A14); also elsewhere on the board
/DDR3/DDR3_BA0: IC301.M3 (BA2); also elsewhere on the board
/DDR3/DDR3_BA1: IC301.N8 (BA1); also elsewhere on the board
/DDR3/DDR3_BA2: IC301.M2 (BA0); also elsewhere on the board
/DDR3/DDR3_CKE: IC301.K9 (CKE); also elsewhere on the board
/DDR3/DDR3_CK_N: IC301.K7 (CK#), R301.2; also elsewhere on the board
/DDR3/DDR3_CK_P: IC301.J7 (CK), R301.1; also elsewhere on the board
/DDR3/DDR3_DM0: IC301.E7 (LDM); also elsewhere on the board
/DDR3/DDR3_DM1: IC301.D3 (UDM); also elsewhere on the board
/DDR3/DDR3_DQ0: IC301.E3 (DQ0); also elsewhere on the board
/DDR3/DDR3_DQ1: IC301.F7 (DQ1); also elsewhere on the board
/DDR3/DDR3_DQ2: IC301.F2 (DQ2); also elsewhere on the board
/DDR3/DDR3_DQ3: IC301.F8 (DQ3); also elsewhere on the board
/DDR3/DDR3_DQ4: IC301.H3 (DQ4); also elsewhere on the board
/DDR3/DDR3_DQ5: IC301.H8 (DQ5); also elsewhere on the board
/DDR3/DDR3_DQ6: IC301.G2 (DQ6); also elsewhere on the board
/DDR3/DDR3_DQ7: IC301.H7 (DQ7); also elsewhere on the board
/DDR3/DDR3_DQ8: IC301.D7 (DQ8); also elsewhere on the board
/DDR3/DDR3_DQ9: IC301.C3 (DQ9); also elsewhere on the board
/DDR3/DDR3_DQ10: IC301.C8 (DQ10); also elsewhere on the board
/DDR3/DDR3_DQ11: IC301.C2 (DQ11); also elsewhere on the board
/DDR3/DDR3_DQ12: IC301.A7 (DQ12); also elsewhere on the board
/DDR3/DDR3_DQ13: IC301.A2 (DQ13); also elsewhere on the board
/DDR3/DDR3_DQ14: IC301.B8 (DQ14); also elsewhere on the board
/DDR3/DDR3_DQ15: IC301.A3 (DQ15); also elsewhere on the board
/DDR3/DDR3_DQS0_N: IC301.G3 (LDQS#); also elsewhere on the board
/DDR3/DDR3_DQS0_P: IC301.F3 (LDQS); also elsewhere on the board
/DDR3/DDR3_DQS1_N: IC301.B7 (UDQS#); also elsewhere on the board
/DDR3/DDR3_DQS1_P: IC301.C7 (UDQS); also elsewhere on the board
/DDR3/DDR3_ODT: IC301.K1 (ODT); also elsewhere on the board
/DDR3/DDR3_nCAS: IC301.K3 (CAS#); also elsewhere on the board
/DDR3/DDR3_nRAS: IC301.J3 (RAS#); also elsewhere on the board
/DDR3/DDR3_nRST: IC301.T2 (RESET#), R306.1; also elsewhere on the board
/DDR3/DDR3_nWE: IC301.L3 (WE#); also elsewhere on the board
/DDR3/DDR_VREF: C318.1, C319.1, C320.2, IC301.H1 (VrefDQ), IC301.M8 (VrefCA), R302.1, R303.1, TP301.1
/GND: C301.2, C302.2, C303.2, C304.1, C305.1, C306.2, C307.2, C308.2, C309.2, C310.2, C311.2, C312.1, C313.1, C314.1, C315.2, C316.2, C317.2, C318.2, C319.2, IC301.A9 (VSS), IC301.B1 (VSSQ), IC301.B3 (VSS), IC301.B9 (VSSQ), IC301.D1 (VSSQ), IC301.D8 (VSSQ), IC301.E1 (VSS), IC301.E2 (VSSQ), IC301.E8 (VSSQ), IC301.F9 (VSSQ), IC301.G1 (VSSQ), IC301.G8 (VSS), IC301.G9 (VSSQ), IC301.J2 (VSS), IC301.J8 (VSS), IC301.M1 (VSS), IC301.M9 (VSS), IC301.P1 (VSS), IC301.P9 (VSS), IC301.T1 (VSS), IC301.T9 (VSS), R303.2, R304.2, R305.1, R306.2; also elsewhere on the board
unnamed: IC301.L2 (CS#), R304.1
unnamed: IC301.L8 (ZQ), R305.2

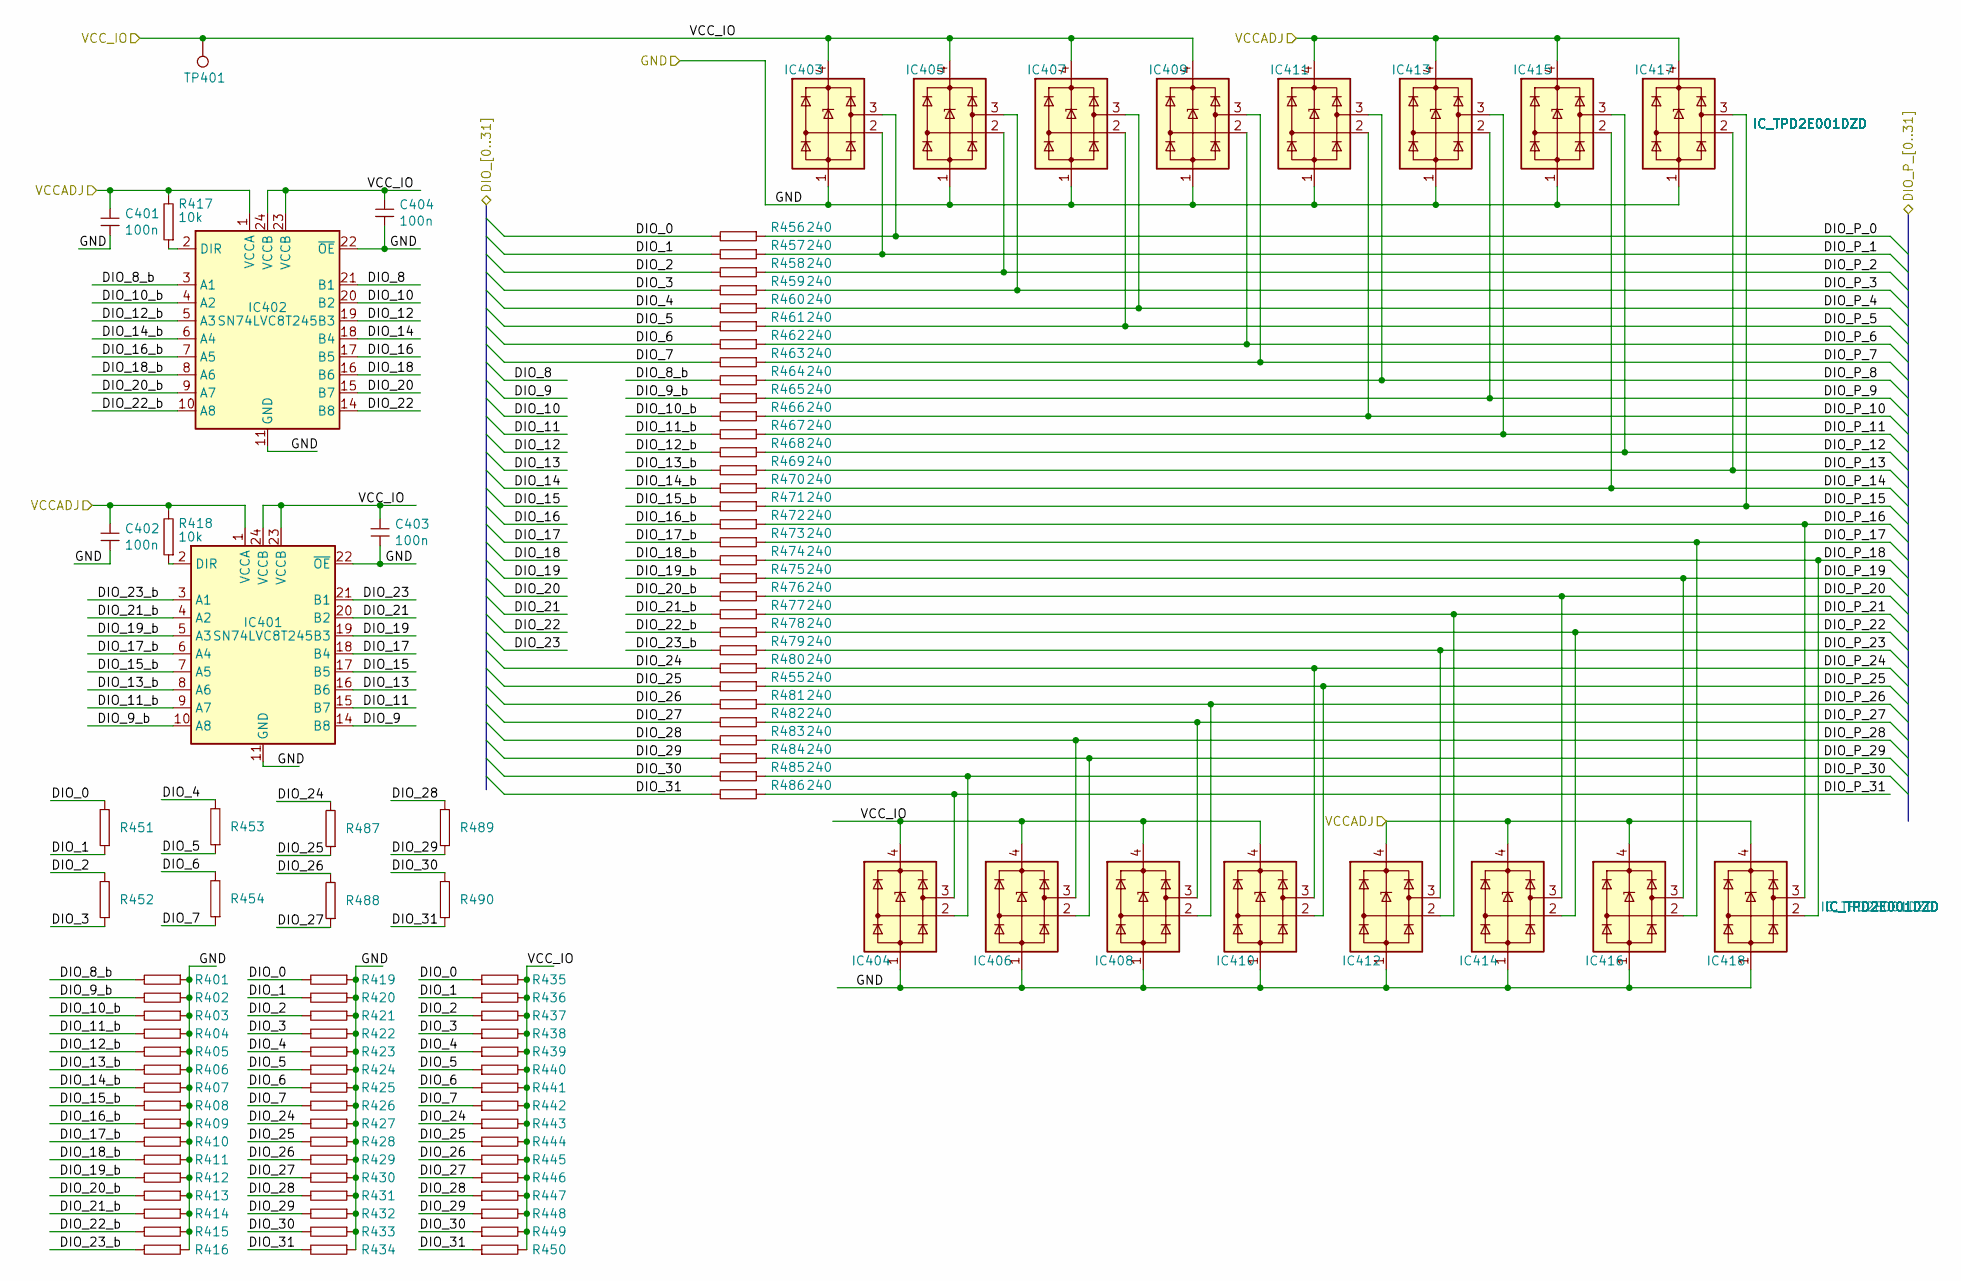
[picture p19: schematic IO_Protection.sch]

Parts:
C401, C402, C403, C404: C_100n_0402_16V; C_0402_1005Metric
IC401, IC402: IC_SN74AVC8T245PW_TSSOP_24; TSSOP-24_4.4x7.8mm_P0.65mm
IC403, IC404, IC405, IC406, IC407, IC408, IC409, IC410, IC411, IC412, IC413, IC414, IC415, IC416, IC417, IC418: IC_TPD2E001DZD; SOT-143(R_PDSO-G4)
R401, R402, R403, R404, R405, R406, R407, R408, R409, R410, R411, R412, R413, R414, R415, R416, R419, R420, R421, R422, R423, R424, R425, R426, R427, R428, R429, R430, R431, R432, R433, R434, R435, R436, R437, R438, R439, R440, R441, R442, R443, R444, R445, R446, R447, R448, R449, R450: R_200k_0402_5%; R_0402_1005Metric
R417, R418: R_10k_0402_5%; R_0402_1005Metric
R451, R452, R453, R454, R487, R488, R489, R490: R_100r_0402_5%; R_0402_1005Metric
R455, R456, R457, R458, R459, R460, R461, R462, R463, R464, R465, R466, R467, R468, R469, R470, R471, R472, R473, R474, R475, R476, R477, R478, R479, R480, R481, R482, R483, R484, R485, R486: R_240r_0402_1%; R_0402_1005Metric
TP401: TestPoint; TestPoint_Pad_D1.0mm

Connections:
/DIO_P_0: IC403.3, R456.2; also elsewhere on the board
/DIO_P_1: IC403.2, R457.2; also elsewhere on the board
/DIO_P_2: IC405.2, R458.2; also elsewhere on the board
/DIO_P_3: IC405.3, R459.2; also elsewhere on the board
/DIO_P_4: IC407.3, R460.2; also elsewhere on the board
/DIO_P_5: IC407.2, R461.2; also elsewhere on the board
/DIO_P_6: IC409.2, R462.2; also elsewhere on the board
/DIO_P_7: IC409.3, R463.2; also elsewhere on the board
/DIO_P_8: IC411.3, R464.2; also elsewhere on the board
/DIO_P_9: IC413.2, R465.2; also elsewhere on the board
/DIO_P_10: IC411.2, R466.2; also elsewhere on the board
/DIO_P_11: IC413.3, R467.2; also elsewhere on the board
/DIO_P_12: IC415.3, R468.2; also elsewhere on the board
/DIO_P_13: IC417.2, R469.2; also elsewhere on the board
/DIO_P_14: IC415.2, R470.2; also elsewhere on the board
/DIO_P_15: IC417.3, R471.2; also elsewhere on the board
/DIO_P_16: IC418.3, R472.2; also elsewhere on the board
/DIO_P_17: IC416.2, R473.2; also elsewhere on the board
/DIO_P_18: IC418.2, R474.2; also elsewhere on the board
/DIO_P_19: IC416.3, R475.2; also elsewhere on the board
/DIO_P_20: IC414.3, R476.2; also elsewhere on the board
/DIO_P_21: IC412.2, R477.2; also elsewhere on the board
/DIO_P_22: IC414.2, R478.2; also elsewhere on the board
/DIO_P_23: IC412.3, R479.2; also elsewhere on the board
/DIO_P_24: IC410.3, R480.2; also elsewhere on the board
/DIO_P_25: IC410.2, R455.2; also elsewhere on the board
/DIO_P_26: IC408.2, R481.2; also elsewhere on the board
/DIO_P_27: IC408.3, R482.2; also elsewhere on the board
/DIO_P_28: IC406.3, R483.2; also elsewhere on the board
/DIO_P_29: IC406.2, R484.2; also elsewhere on the board
/DIO_P_30: IC404.2, R485.2; also elsewhere on the board
/DIO_P_31: IC404.3, R486.2; also elsewhere on the board
/FPGA_Bank/DIO_0: R419.1, R435.2, R451.1, R456.1; also elsewhere on the board
/FPGA_Bank/DIO_1: R420.1, R436.2, R451.2, R457.1; also elsewhere on the board
/FPGA_Bank/DIO_2: R421.1, R437.2, R452.1, R458.1; also elsewhere on the board
/FPGA_Bank/DIO_3: R422.1, R438.2, R452.2, R459.1; also elsewhere on the board
/FPGA_Bank/DIO_4: R423.1, R439.2, R453.1, R460.1; also elsewhere on the board
/FPGA_Bank/DIO_5: R424.1, R440.2, R453.2, R461.1; also elsewhere on the board
/FPGA_Bank/DIO_6: R425.1, R441.2, R454.1, R462.1; also elsewhere on the board
/FPGA_Bank/DIO_7: R426.1, R442.2, R454.2, R463.1; also elsewhere on the board
/FPGA_Bank/DIO_8: IC402.21 (B1); also elsewhere on the board
/FPGA_Bank/DIO_9: IC401.14 (B8); also elsewhere on the board
/FPGA_Bank/DIO_10: IC402.20 (B2); also elsewhere on the board
/FPGA_Bank/DIO_11: IC401.15 (B7); also elsewhere on the board
/FPGA_Bank/DIO_12: IC402.19 (B3); also elsewhere on the board
/FPGA_Bank/DIO_13: IC401.16 (B6); also elsewhere on the board
/FPGA_Bank/DIO_14: IC402.18 (B4); also elsewhere on the board
/FPGA_Bank/DIO_15: IC401.17 (B5); also elsewhere on the board
/FPGA_Bank/DIO_16: IC402.17 (B5); also elsewhere on the board
/FPGA_Bank/DIO_17: IC401.18 (B4); also elsewhere on the board
/FPGA_Bank/DIO_18: IC402.16 (B6); also elsewhere on the board
/FPGA_Bank/DIO_19: IC401.19 (B3); also elsewhere on the board
/FPGA_Bank/DIO_20: IC402.15 (B7); also elsewhere on the board
/FPGA_Bank/DIO_21: IC401.20 (B2); also elsewhere on the board
/FPGA_Bank/DIO_22: IC402.14 (B8); also elsewhere on the board
/FPGA_Bank/DIO_23: IC401.21 (B1); also elsewhere on the board
/FPGA_Bank/DIO_24: R427.1, R443.2, R480.1, R487.1; also elsewhere on the board
/FPGA_Bank/DIO_25: R428.1, R444.2, R455.1, R487.2; also elsewhere on the board
/FPGA_Bank/DIO_26: R429.1, R445.2, R481.1, R488.1; also elsewhere on the board
/FPGA_Bank/DIO_27: R430.1, R446.2, R482.1, R488.2; also elsewhere on the board
/FPGA_Bank/DIO_28: R431.1, R447.2, R483.1, R489.1; also elsewhere on the board
/FPGA_Bank/DIO_29: R432.1, R448.2, R484.1, R489.2; also elsewhere on the board
/FPGA_Bank/DIO_30: R433.1, R449.2, R485.1, R490.1; also elsewhere on the board
/FPGA_Bank/DIO_31: R434.1, R450.2, R486.1, R490.2; also elsewhere on the board
/GND: C401.2, C402.2, C403.2, C404.2, IC401.11 (GND), IC401.12 (GND), IC401.13 (GND), IC401.22 (~OE), IC402.11 (GND), IC402.12 (GND), IC402.13 (GND), IC402.22 (~OE), IC403.1, IC404.1, IC405.1, IC406.1, IC407.1, IC408.1, IC409.1, IC410.1, IC411.1, IC412.1, IC413.1, IC414.1, IC415.1, IC416.1, IC417.1, IC418.1, R401.2, R402.2, R403.2, R404.2, R405.2, R406.2, R407.2, R408.2, R409.2, R410.2, R411.2, R412.2, R413.2, R414.2, R415.2, R416.2, R419.2, R420.2, R421.2, R422.2, R423.2, R424.2, R425.2, R426.2, R427.2, R428.2, R429.2, R430.2, R431.2, R432.2, R433.2, R434.2; also elsewhere on the board
/IO_Protection/DIO_8_b: IC402.3 (A1), R401.1, R464.1
/IO_Protection/DIO_9_b: IC401.10 (A8), R402.1, R465.1
/IO_Protection/DIO_10_b: IC402.4 (A2), R403.1, R466.1
/IO_Protection/DIO_11_b: IC401.9 (A7), R404.1, R467.1
/IO_Protection/DIO_12_b: IC402.5 (A3), R405.1, R468.1
/IO_Protection/DIO_13_b: IC401.8 (A6), R406.1, R469.1
/IO_Protection/DIO_14_b: IC402.6 (A4), R407.1, R470.1
/IO_Protection/DIO_15_b: IC401.7 (A5), R408.1, R471.1
/IO_Protection/DIO_16_b: IC402.7 (A5), R409.1, R472.1
/IO_Protection/DIO_17_b: IC401.6 (A4), R410.1, R473.1
/IO_Protection/DIO_18_b: IC402.8 (A6), R411.1, R474.1
/IO_Protection/DIO_19_b: IC401.5 (A3), R412.1, R475.1
/IO_Protection/DIO_20_b: IC402.9 (A7), R413.1, R476.1
/IO_Protection/DIO_21_b: IC401.4 (A2), R414.1, R477.1
/IO_Protection/DIO_22_b: IC402.10 (A8), R415.1, R478.1
/IO_Protection/DIO_23_b: IC401.3 (A1), R416.1, R479.1
/IO_Protection/VCCADJ: C401.1, C402.1, IC401.1 (VCCA), IC402.1 (VCCA), IC411.4, IC412.4, IC413.4, IC414.4, IC415.4, IC416.4, IC417.4, IC418.4, R417.1, R418.1; also elsewhere on the board
/VCC_IO: C403.1, C404.1, IC401.23 (VCCB), IC401.24 (VCCB), IC402.23 (VCCB), IC402.24 (VCCB), IC403.4, IC404.4, IC405.4, IC406.4, IC407.4, IC408.4, IC409.4, IC410.4, R435.1, R436.1, R437.1, R438.1, R439.1, R440.1, R441.1, R442.1, R443.1, R444.1, R445.1, R446.1, R447.1, R448.1, R449.1, R450.1, TP401.1; also elsewhere on the board
unnamed: IC401.2 (DIR), R418.2
unnamed: IC402.2 (DIR), R417.2

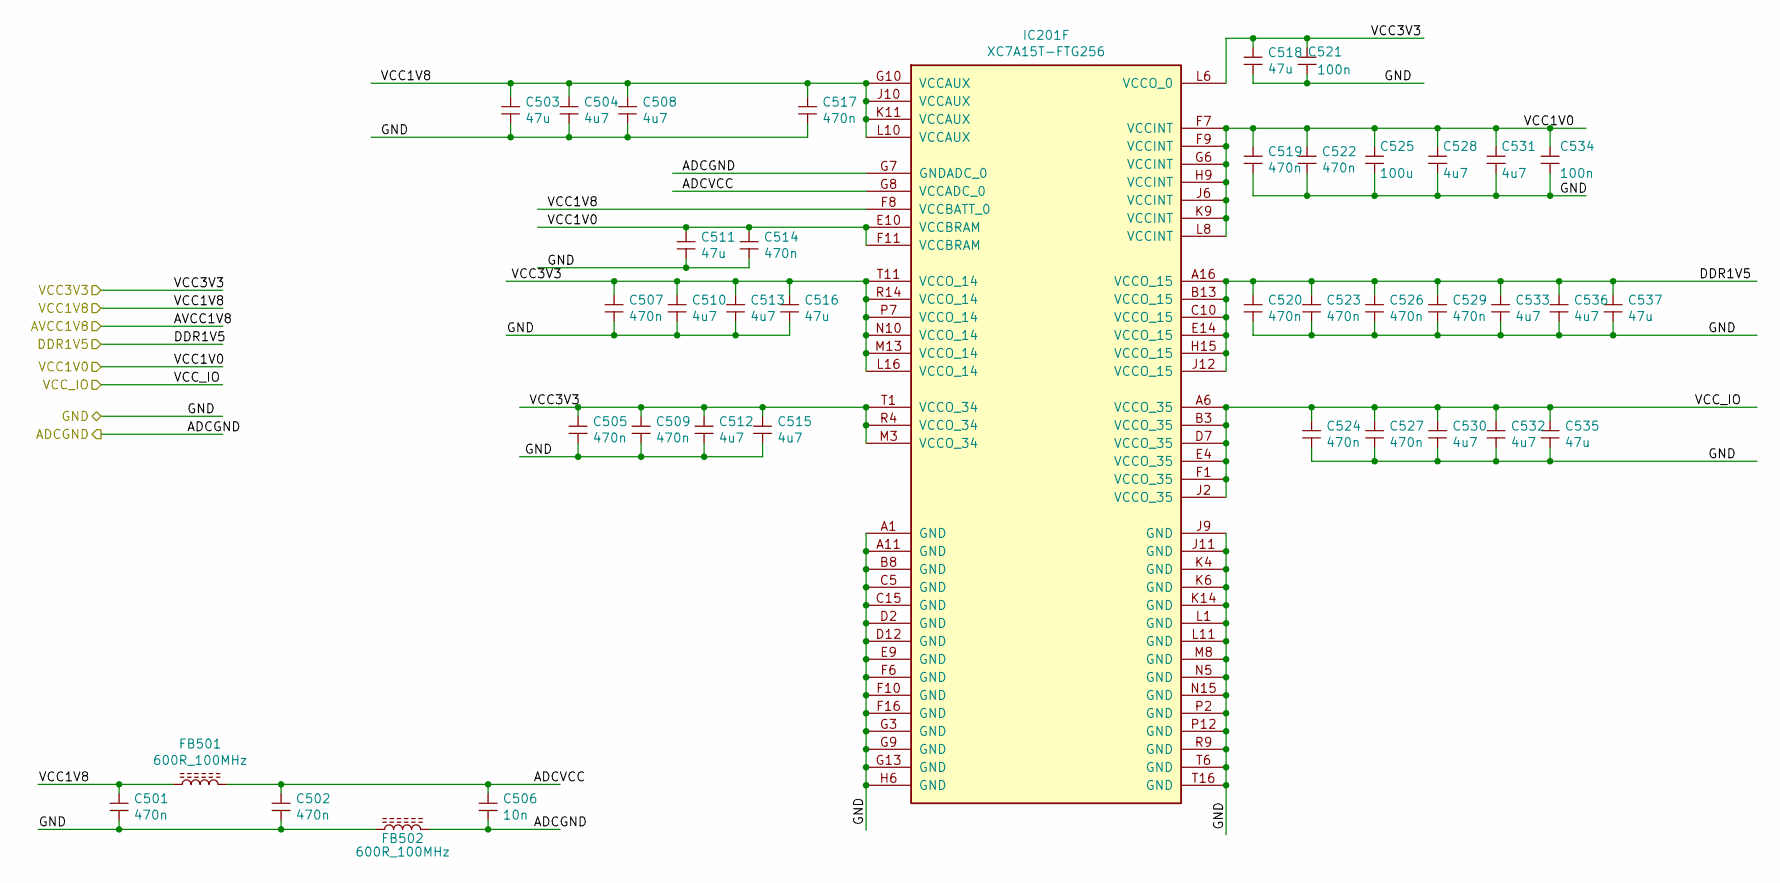
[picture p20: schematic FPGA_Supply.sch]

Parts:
C501, C502, C505, C507, C509, C517, C519, C520, C522, C523, C524, C526, C527, C529: C_470n_0402_6V3; C_0402_1005Metric
C503, C511, C516, C518, C535, C537: C_47u_0603_6V3; C_0603_1608Metric_Pad1.05x0.95mm_HandSolder
C504, C508, C510, C512, C513, C515, C528, C530, C531, C532, C533, C536: C_4u7_0402_6V3; C_0402_1005Metric
C506: C_10n_0402_16V; C_0402_1005Metric
C514: C_470n_0603_16V; C_0603_1608Metric_Pad1.05x0.95mm_HandSolder
C521, C534: C_100n_0402_16V; C_0402_1005Metric
C525: C_100u_1206_6V3; C_1206_3216Metric_Pad1.42x1.75mm_HandSolder
FB501, FB502: FB_600R_100MHz_0,5A; L_0402_1005Metric
IC201: IC_XC7A15T_FTG256; Xilinx_FTG256

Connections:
/DDR3/DDR1V5: C520.1, C523.1, C526.1, C529.1, C533.1, C536.1, C537.1, IC201.A16 (VCCO_15), IC201.B13 (VCCO_15), IC201.C10 (VCCO_15), IC201.E14 (VCCO_15), IC201.H15 (VCCO_15), IC201.J12 (VCCO_15); also elsewhere on the board
/FPGA_Cornfig/ADCGND: C506.2, FB502.2, IC201.G7 (GNDADC_0); also elsewhere on the board
/FPGA_Supply/ADCVCC: C502.1, C506.1, FB501.2, IC201.G8 (VCCADC_0)
/FPGA_Supply/VCC1V0: C511.1, C514.1, C519.1, C522.1, C525.1, C528.1, C531.1, C534.1, IC201.E10 (VCCBRAM), IC201.F7 (VCCINT), IC201.F9 (VCCINT), IC201.F11 (VCCBRAM), IC201.G6 (VCCINT), IC201.H9 (VCCINT), IC201.J6 (VCCINT), IC201.K9 (VCCINT), IC201.L8 (VCCINT); also elsewhere on the board
/FPGA_Supply/VCC1V8: C501.1, C503.1, C504.1, C508.1, C517.1, FB501.1, IC201.F8 (VCCBATT_0), IC201.G10 (VCCAUX), IC201.J10 (VCCAUX), IC201.K11 (VCCAUX), IC201.L10 (VCCAUX); also elsewhere on the board
/GND: C501.2, C502.2, C503.2, C504.2, C505.2, C507.2, C508.2, C509.2, C510.2, C511.2, C512.2, C513.2, C514.2, C515.2, C516.2, C517.2, C518.2, C519.2, C520.2, C521.2, C522.2, C523.2, C524.2, C525.2, C526.2, C527.2, C528.2, C529.2, C530.2, C531.2, C532.2, C533.2, C534.2, C535.2, C536.2, C537.2, FB502.1, IC201.A1 (GND), IC201.A11 (GND), IC201.B8 (GND), IC201.C5 (GND), IC201.C15 (GND), IC201.D2 (GND), IC201.D12 (GND), IC201.E9 (GND), IC201.F6 (GND), IC201.F10 (GND), IC201.F16 (GND), IC201.G3 (GND), IC201.G9 (GND), IC201.G13 (GND), IC201.H6 (GND), IC201.J9 (GND), IC201.J11 (GND), IC201.K4 (GND), IC201.K6 (GND), IC201.K14 (GND), IC201.L1 (GND), IC201.L11 (GND), IC201.M8 (GND), IC201.N5 (GND), IC201.N15 (GND), IC201.P2 (GND), IC201.P12 (GND), IC201.R9 (GND), IC201.T6 (GND), IC201.T16 (GND); also elsewhere on the board
/VCC_IO: C524.1, C527.1, C530.1, C532.1, C535.1, IC201.A6 (VCCO_35), IC201.B3 (VCCO_35), IC201.D7 (VCCO_35), IC201.E4 (VCCO_35), IC201.F1 (VCCO_35), IC201.J2 (VCCO_35); also elsewhere on the board

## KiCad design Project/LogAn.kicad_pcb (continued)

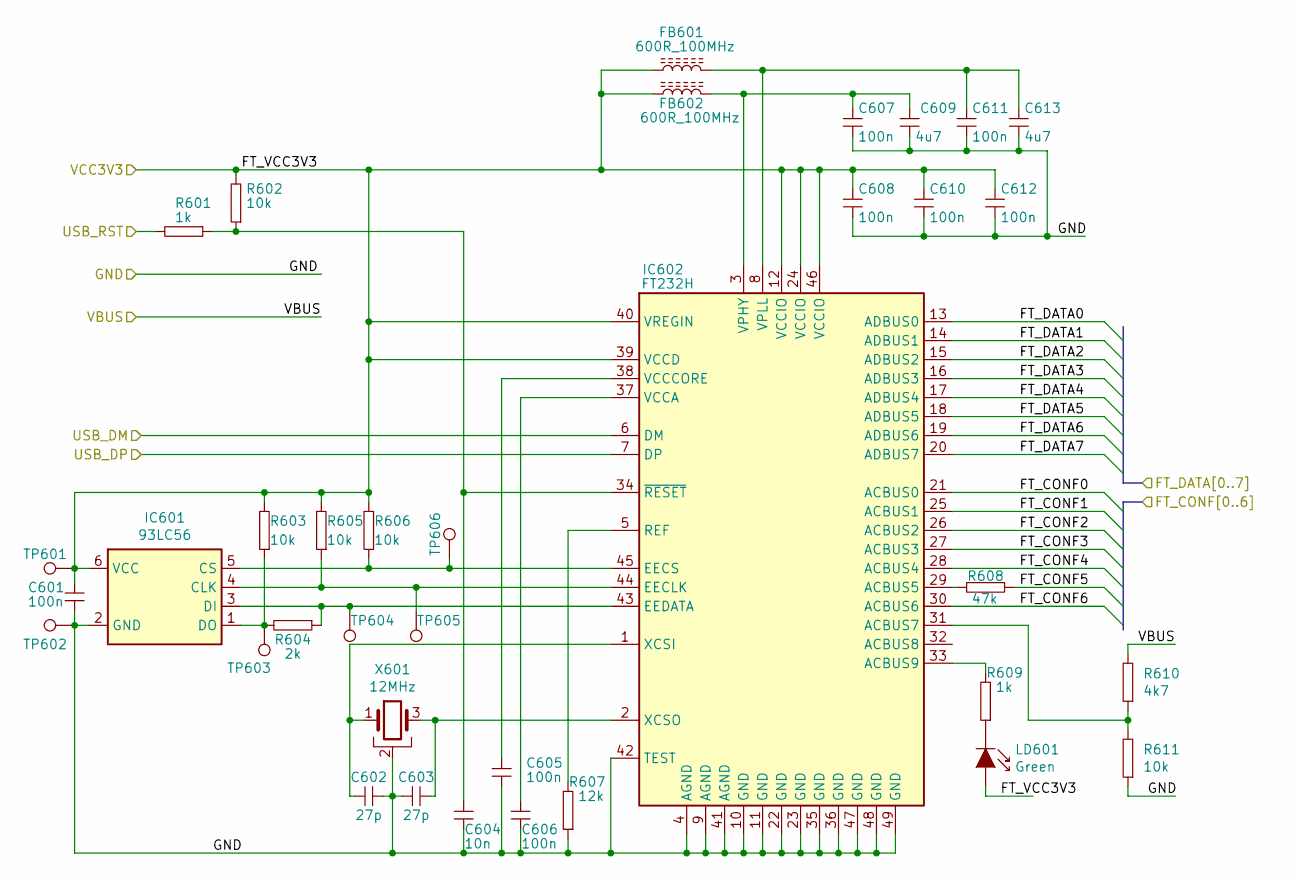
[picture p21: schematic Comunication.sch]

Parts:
C601, C605, C606, C607, C608, C610, C611, C612: C_100n_0402_16V; C_0402_1005Metric
C602, C603: C_27p_0402_16V; C_0402_1005Metric
C604: C_10n_0402_16V; C_0402_1005Metric
C609, C613: C_4u7_0402_6V3; C_0402_1005Metric
FB601, FB602: FB_600R_100MHz_0,5A; L_0402_1005Metric
IC601: IC_93LC56BT-1OT; SOT-23-6
IC602: IC_FT232H_QFN48; QFN-48-1EP_8x8mm_P0.5mm_EP6.2x6.2mm
LD601: LED_Green_0603; LED_0603_1608Metric
R601, R609: R_1k_0402_5%; R_0402_1005Metric
R602, R603, R605, R606, R611: R_10k_0402_5%; R_0402_1005Metric
R604: R_2k_0402_5%; R_0402_1005Metric
R607: R_12k_0402_1%; R_0402_1005Metric
R608: R_27k_0402_5%; R_0402_1005Metric
R610: R_4k7_0402_5%; R_0402_1005Metric
TP601, TP602, TP603, TP604, TP605, TP606: TestPoint; TestPoint_Pad_D1.0mm
X601: X_Crystal_12MHz_3_2x2_5; Crystal_SMD_3225-4Pin_3.2x2.5mm

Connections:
/Comunication/FT_CONF0: IC602.21 (ACBUS0); also elsewhere on the board
/Comunication/FT_CONF1: IC602.25 (ACBUS1); also elsewhere on the board
/Comunication/FT_CONF2: IC602.26 (ACBUS2); also elsewhere on the board
/Comunication/FT_CONF3: IC602.27 (ACBUS3); also elsewhere on the board
/Comunication/FT_CONF4: IC602.28 (ACBUS4); also elsewhere on the board
/Comunication/FT_CONF5: R608.2; also elsewhere on the board
/Comunication/FT_CONF6: IC602.30 (ACBUS6); also elsewhere on the board
/Comunication/FT_DATA0: IC602.13 (ADBUS0); also elsewhere on the board
/Comunication/FT_DATA1: IC602.14 (ADBUS1); also elsewhere on the board
/Comunication/FT_DATA2: IC602.15 (ADBUS2); also elsewhere on the board
/Comunication/FT_DATA3: IC602.16 (ADBUS3); also elsewhere on the board
/Comunication/FT_DATA4: IC602.17 (ADBUS4); also elsewhere on the board
/Comunication/FT_DATA5: IC602.18 (ADBUS5); also elsewhere on the board
/Comunication/FT_DATA6: IC602.19 (ADBUS6); also elsewhere on the board
/Comunication/FT_DATA7: IC602.20 (ADBUS7); also elsewhere on the board
/Comunication/USB_DM: IC602.6 (DM); also elsewhere on the board
/Comunication/USB_DP: IC602.7 (DP); also elsewhere on the board
/Comunication/USB_RST: R601.1; also elsewhere on the board
/Comunication/VBUS: R610.1; also elsewhere on the board
/GND: C601.2, C602.2, C603.1, C604.2, C605.2, C606.2, C607.2, C608.2, C609.2, C610.2, C611.2, C612.2, C613.2, IC601.2 (GND), IC602.4 (AGND), IC602.9 (AGND), IC602.10 (GND), IC602.11 (GND), IC602.22 (GND), IC602.23 (GND), IC602.35 (GND), IC602.36 (GND), IC602.41 (AGND), IC602.42 (TEST), IC602.47 (GND), IC602.48 (GND), IC602.49 (GND), R607.2, R611.2, TP602.1, X601.2, X601.4; also elsewhere on the board
unnamed: C602.1, IC602.1 (XCSI), X601.1
unnamed: C603.2, IC602.2 (XCSO), X601.3
unnamed: C604.1, IC602.34 (~RESET), R601.2, R602.2
unnamed: C605.1, IC602.38 (VCCCORE)
unnamed: C606.1, IC602.37 (VCCA)
unnamed: C607.1, C609.1, FB602.2, IC602.3 (VPHY)
unnamed: C611.1, C613.1, FB601.2, IC602.8 (VPLL)
unnamed: IC601.1 (DO), R603.2, R604.1, TP603.1
unnamed: IC601.3 (DI), IC602.43 (EEDATA), R604.2, TP604.1
unnamed: IC601.4 (CLK), IC602.44 (EECLK), R605.2, TP605.1
unnamed: IC601.5 (CS), IC602.45 (EECS), R606.2, TP606.1
unnamed: IC602.5 (REF), R607.1
unnamed: IC602.29 (ACBUS5), R608.1
unnamed: IC602.31 (ACBUS7), R610.2, R611.1
unnamed: IC602.33 (ACBUS9), R609.1
unnamed: LD601.1 (K), R609.2

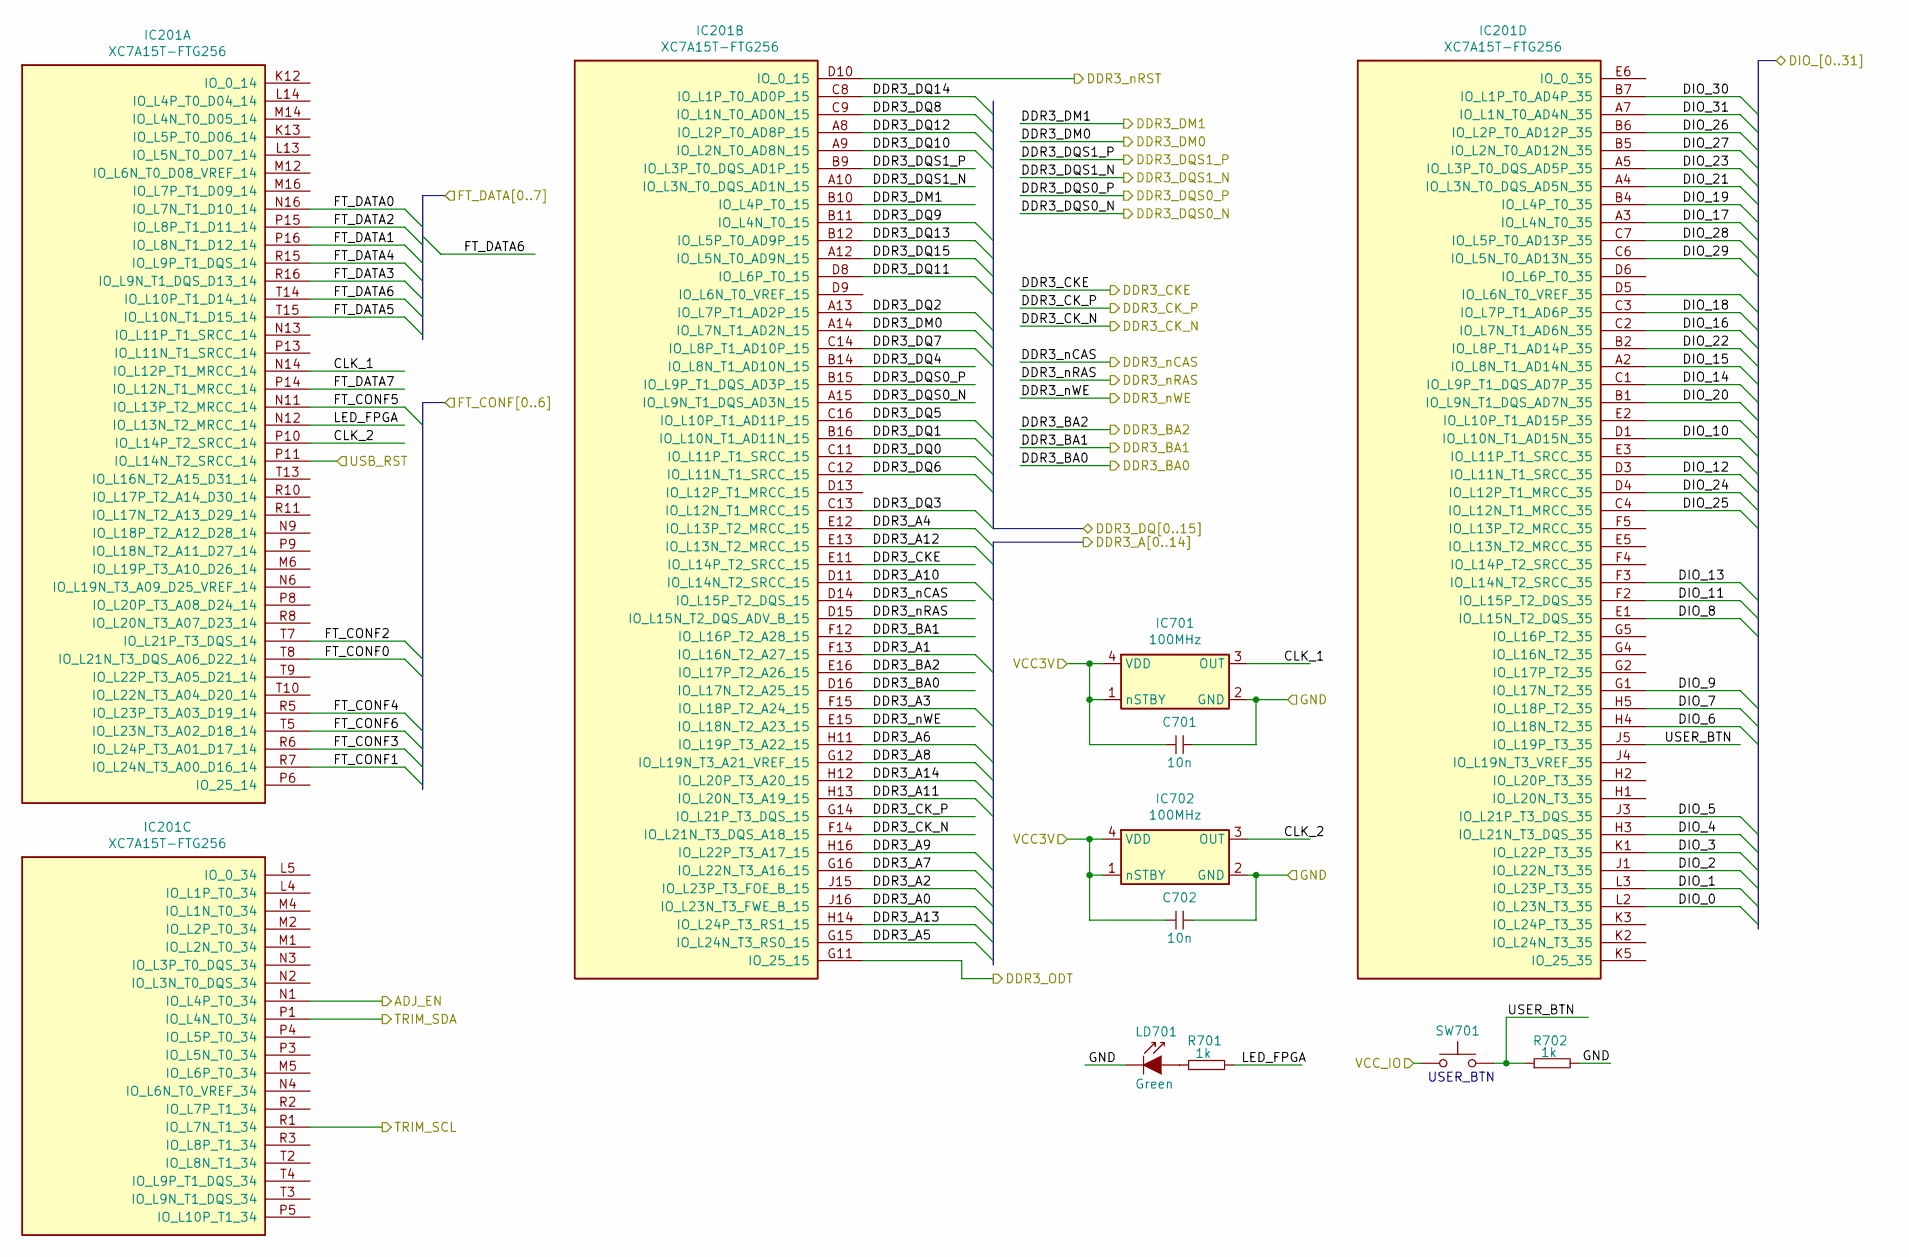
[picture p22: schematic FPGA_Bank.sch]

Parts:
C701, C702: C_10n_0402_16V; C_0402_1005Metric
IC201: IC_XC7A15T_FTG256; Xilinx_FTG256
IC701, IC702: IC_ASEM1_100MHZ_3.2_2.5; OSC_SMD_3225-4Pin_3.2x2.5mm
LD701: LED_Green_0603; LED_0603_1608Metric
R701, R702: R_1k_0402_5%; R_0402_1005Metric
SW701: SW_B3U-1000PM-B; SW_SPST_B3U-1000P-B

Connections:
/Comunication/FT_CONF0: IC201.T8 (IO_L21N_T3_DQS_A06_D22_14); also elsewhere on the board
/Comunication/FT_CONF1: IC201.R7 (IO_L24N_T3_A00_D16_14); also elsewhere on the board
/Comunication/FT_CONF2: IC201.T7 (IO_L21P_T3_DQS_14); also elsewhere on the board
/Comunication/FT_CONF3: IC201.R6 (IO_L24P_T3_A01_D17_14); also elsewhere on the board
/Comunication/FT_CONF4: IC201.R5 (IO_L23P_T3_A03_D19_14); also elsewhere on the board
/Comunication/FT_CONF5: IC201.N11 (IO_L13P_T2_MRCC_14); also elsewhere on the board
/Comunication/FT_CONF6: IC201.T5 (IO_L23N_T3_A02_D18_14); also elsewhere on the board
/Comunication/FT_DATA0: IC201.N16 (IO_L7N_T1_D10_14); also elsewhere on the board
/Comunication/FT_DATA1: IC201.P16 (IO_L8N_T1_D12_14); also elsewhere on the board
/Comunication/FT_DATA2: IC201.P15 (IO_L8P_T1_D11_14); also elsewhere on the board
/Comunication/FT_DATA3: IC201.R16 (IO_L9N_T1_DQS_D13_14); also elsewhere on the board
/Comunication/FT_DATA4: IC201.R15 (IO_L9P_T1_DQS_14); also elsewhere on the board
/Comunication/FT_DATA5: IC201.T15 (IO_L10N_T1_D15_14); also elsewhere on the board
/Comunication/FT_DATA6: IC201.T14 (IO_L10P_T1_D14_14); also elsewhere on the board
/Comunication/FT_DATA7: IC201.P14 (IO_L12N_T1_MRCC_14); also elsewhere on the board
/Comunication/USB_RST: IC201.P11 (IO_L14N_T2_SRCC_14); also elsewhere on the board
/DDR3/DDR3_A0: IC201.J16 (IO_L23N_T3_FWE_B_15); also elsewhere on the board
/DDR3/DDR3_A1: IC201.F13 (IO_L16N_T2_A27_15); also elsewhere on the board
/DDR3/DDR3_A2: IC201.J15 (IO_L23P_T3_FOE_B_15); also elsewhere on the board
/DDR3/DDR3_A3: IC201.F15 (IO_L18P_T2_A24_15); also elsewhere on the board
/DDR3/DDR3_A4: IC201.E12 (IO_L13P_T2_MRCC_15); also elsewhere on the board
/DDR3/DDR3_A5: IC201.G15 (IO_L24N_T3_RS0_15); also elsewhere on the board
/DDR3/DDR3_A6: IC201.H11 (IO_L19P_T3_A22_15); also elsewhere on the board
/DDR3/DDR3_A7: IC201.G16 (IO_L22N_T3_A16_15); also elsewhere on the board
/DDR3/DDR3_A8: IC201.G12 (IO_L19N_T3_A21_VREF_15); also elsewhere on the board
/DDR3/DDR3_A9: IC201.H16 (IO_L22P_T3_A17_15); also elsewhere on the board
/DDR3/DDR3_A10: IC201.D11 (IO_L14N_T2_SRCC_15); also elsewhere on the board
/DDR3/DDR3_A11: IC201.H13 (IO_L20N_T3_A19_15); also elsewhere on the board
/DDR3/DDR3_A12: IC201.E13 (IO_L13N_T2_MRCC_15); also elsewhere on the board
/DDR3/DDR3_A13: IC201.H14 (IO_L24P_T3_RS1_15); also elsewhere on the board
/DDR3/DDR3_A14: IC201.H12 (IO_L20P_T3_A20_15); also elsewhere on the board
/DDR3/DDR3_BA0: IC201.D16 (IO_L17N_T2_A25_15); also elsewhere on the board
/DDR3/DDR3_BA1: IC201.F12 (IO_L16P_T2_A28_15); also elsewhere on the board
/DDR3/DDR3_BA2: IC201.E16 (IO_L17P_T2_A26_15); also elsewhere on the board
/DDR3/DDR3_CKE: IC201.E11 (IO_L14P_T2_SRCC_15); also elsewhere on the board
/DDR3/DDR3_CK_N: IC201.F14 (IO_L21N_T3_DQS_A18_15); also elsewhere on the board
/DDR3/DDR3_CK_P: IC201.G14 (IO_L21P_T3_DQS_15); also elsewhere on the board
/DDR3/DDR3_DM0: IC201.A14 (IO_L7N_T1_AD2N_15); also elsewhere on the board
/DDR3/DDR3_DM1: IC201.B10 (IO_L4P_T0_15); also elsewhere on the board
/DDR3/DDR3_DQ0: IC201.C11 (IO_L11P_T1_SRCC_15); also elsewhere on the board
/DDR3/DDR3_DQ1: IC201.B16 (IO_L10N_T1_AD11N_15); also elsewhere on the board
/DDR3/DDR3_DQ2: IC201.A13 (IO_L7P_T1_AD2P_15); also elsewhere on the board
/DDR3/DDR3_DQ3: IC201.C13 (IO_L12N_T1_MRCC_15); also elsewhere on the board
/DDR3/DDR3_DQ4: IC201.B14 (IO_L8N_T1_AD10N_15); also elsewhere on the board
/DDR3/DDR3_DQ5: IC201.C16 (IO_L10P_T1_AD11P_15); also elsewhere on the board
/DDR3/DDR3_DQ6: IC201.C12 (IO_L11N_T1_SRCC_15); also elsewhere on the board
/DDR3/DDR3_DQ7: IC201.C14 (IO_L8P_T1_AD10P_15); also elsewhere on the board
/DDR3/DDR3_DQ8: IC201.C9 (IO_L1N_T0_AD0N_15); also elsewhere on the board
/DDR3/DDR3_DQ9: IC201.B11 (IO_L4N_T0_15); also elsewhere on the board
/DDR3/DDR3_DQ10: IC201.A9 (IO_L2N_T0_AD8N_15); also elsewhere on the board
/DDR3/DDR3_DQ11: IC201.D8 (IO_L6P_T0_15); also elsewhere on the board
/DDR3/DDR3_DQ12: IC201.A8 (IO_L2P_T0_AD8P_15); also elsewhere on the board
/DDR3/DDR3_DQ13: IC201.B12 (IO_L5P_T0_AD9P_15); also elsewhere on the board
/DDR3/DDR3_DQ14: IC201.C8 (IO_L1P_T0_AD0P_15); also elsewhere on the board
/DDR3/DDR3_DQ15: IC201.A12 (IO_L5N_T0_AD9N_15); also elsewhere on the board
/DDR3/DDR3_DQS0_N: IC201.A15 (IO_L9N_T1_DQS_AD3N_15); also elsewhere on the board
/DDR3/DDR3_DQS0_P: IC201.B15 (IO_L9P_T1_DQS_AD3P_15); also elsewhere on the board
/DDR3/DDR3_DQS1_N: IC201.A10 (IO_L3N_T0_DQS_AD1N_15); also elsewhere on the board
/DDR3/DDR3_DQS1_P: IC201.B9 (IO_L3P_T0_DQS_AD1P_15); also elsewhere on the board
/DDR3/DDR3_ODT: IC201.G11 (IO_25_15); also elsewhere on the board
/DDR3/DDR3_nCAS: IC201.D14 (IO_L15P_T2_DQS_15); also elsewhere on the board
/DDR3/DDR3_nRAS: IC201.D15 (IO_L15N_T2_DQS_ADV_B_15); also elsewhere on the board
/DDR3/DDR3_nRST: IC201.D10 (IO_0_15); also elsewhere on the board
/DDR3/DDR3_nWE: IC201.E15 (IO_L18N_T2_A23_15); also elsewhere on the board
/FPGA_Bank/ADJ_EN: IC201.N1 (IO_L4P_T0_34); also elsewhere on the board
/FPGA_Bank/CLK_1: IC201.N14 (IO_L12P_T1_MRCC_14), IC701.3 (OUT)
/FPGA_Bank/CLK_2: IC201.P10 (IO_L14P_T2_SRCC_14), IC702.3 (OUT)
/FPGA_Bank/DIO_0: IC201.L2 (IO_L23N_T3_35); also elsewhere on the board
/FPGA_Bank/DIO_1: IC201.L3 (IO_L23P_T3_35); also elsewhere on the board
/FPGA_Bank/DIO_2: IC201.J1 (IO_L22N_T3_35); also elsewhere on the board
/FPGA_Bank/DIO_3: IC201.K1 (IO_L22P_T3_35); also elsewhere on the board
/FPGA_Bank/DIO_4: IC201.H3 (IO_L21N_T3_DQS_35); also elsewhere on the board
/FPGA_Bank/DIO_5: IC201.J3 (IO_L21P_T3_DQS_35); also elsewhere on the board
/FPGA_Bank/DIO_6: IC201.H4 (IO_L18N_T2_35); also elsewhere on the board
/FPGA_Bank/DIO_7: IC201.H5 (IO_L18P_T2_35); also elsewhere on the board
/FPGA_Bank/DIO_8: IC201.E1 (IO_L15N_T2_DQS_35); also elsewhere on the board
/FPGA_Bank/DIO_9: IC201.G1 (IO_L17N_T2_35); also elsewhere on the board
/FPGA_Bank/DIO_10: IC201.D1 (IO_L10N_T1_AD15N_35); also elsewhere on the board
/FPGA_Bank/DIO_11: IC201.F2 (IO_L15P_T2_DQS_35); also elsewhere on the board
/FPGA_Bank/DIO_12: IC201.D3 (IO_L11N_T1_SRCC_35); also elsewhere on the board
/FPGA_Bank/DIO_13: IC201.F3 (IO_L14N_T2_SRCC_35); also elsewhere on the board
/FPGA_Bank/DIO_14: IC201.C1 (IO_L9P_T1_DQS_AD7P_35); also elsewhere on the board
/FPGA_Bank/DIO_15: IC201.A2 (IO_L8N_T1_AD14N_35); also elsewhere on the board
/FPGA_Bank/DIO_16: IC201.C2 (IO_L7N_T1_AD6N_35); also elsewhere on the board
/FPGA_Bank/DIO_17: IC201.A3 (IO_L4N_T0_35); also elsewhere on the board
/FPGA_Bank/DIO_18: IC201.C3 (IO_L7P_T1_AD6P_35); also elsewhere on the board
/FPGA_Bank/DIO_19: IC201.B4 (IO_L4P_T0_35); also elsewhere on the board
/FPGA_Bank/DIO_20: IC201.B1 (IO_L9N_T1_DQS_AD7N_35); also elsewhere on the board
/FPGA_Bank/DIO_21: IC201.A4 (IO_L3N_T0_DQS_AD5N_35); also elsewhere on the board
/FPGA_Bank/DIO_22: IC201.B2 (IO_L8P_T1_AD14P_35); also elsewhere on the board
/FPGA_Bank/DIO_23: IC201.A5 (IO_L3P_T0_DQS_AD5P_35); also elsewhere on the board
/FPGA_Bank/DIO_24: IC201.D4 (IO_L12P_T1_MRCC_35); also elsewhere on the board
/FPGA_Bank/DIO_25: IC201.C4 (IO_L12N_T1_MRCC_35); also elsewhere on the board
/FPGA_Bank/DIO_26: IC201.B6 (IO_L2P_T0_AD12P_35); also elsewhere on the board
/FPGA_Bank/DIO_27: IC201.B5 (IO_L2N_T0_AD12N_35); also elsewhere on the board
/FPGA_Bank/DIO_28: IC201.C7 (IO_L5P_T0_AD13P_35); also elsewhere on the board
/FPGA_Bank/DIO_29: IC201.C6 (IO_L5N_T0_AD13N_35); also elsewhere on the board
/FPGA_Bank/DIO_30: IC201.B7 (IO_L1P_T0_AD4P_35); also elsewhere on the board
/FPGA_Bank/DIO_31: IC201.A7 (IO_L1N_T0_AD4N_35); also elsewhere on the board
/FPGA_Bank/LED_FPGA: IC201.N12 (IO_L13N_T2_MRCC_14), R701.1
/FPGA_Bank/TRIM_SCL: IC201.R1 (IO_L7N_T1_34); also elsewhere on the board
/FPGA_Bank/TRIM_SDA: IC201.P1 (IO_L4N_T0_34); also elsewhere on the board
/FPGA_Bank/USER_BTN: IC201.J5 (IO_L19P_T3_35), R702.2, SW701.1
/GND: C701.2, C702.2, IC701.2 (GND), IC702.2 (GND), LD701.1 (K), R702.1; also elsewhere on the board
/VCC_IO: SW701.2; also elsewhere on the board
unnamed: LD701.2 (A), R701.2

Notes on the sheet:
USER_BTN

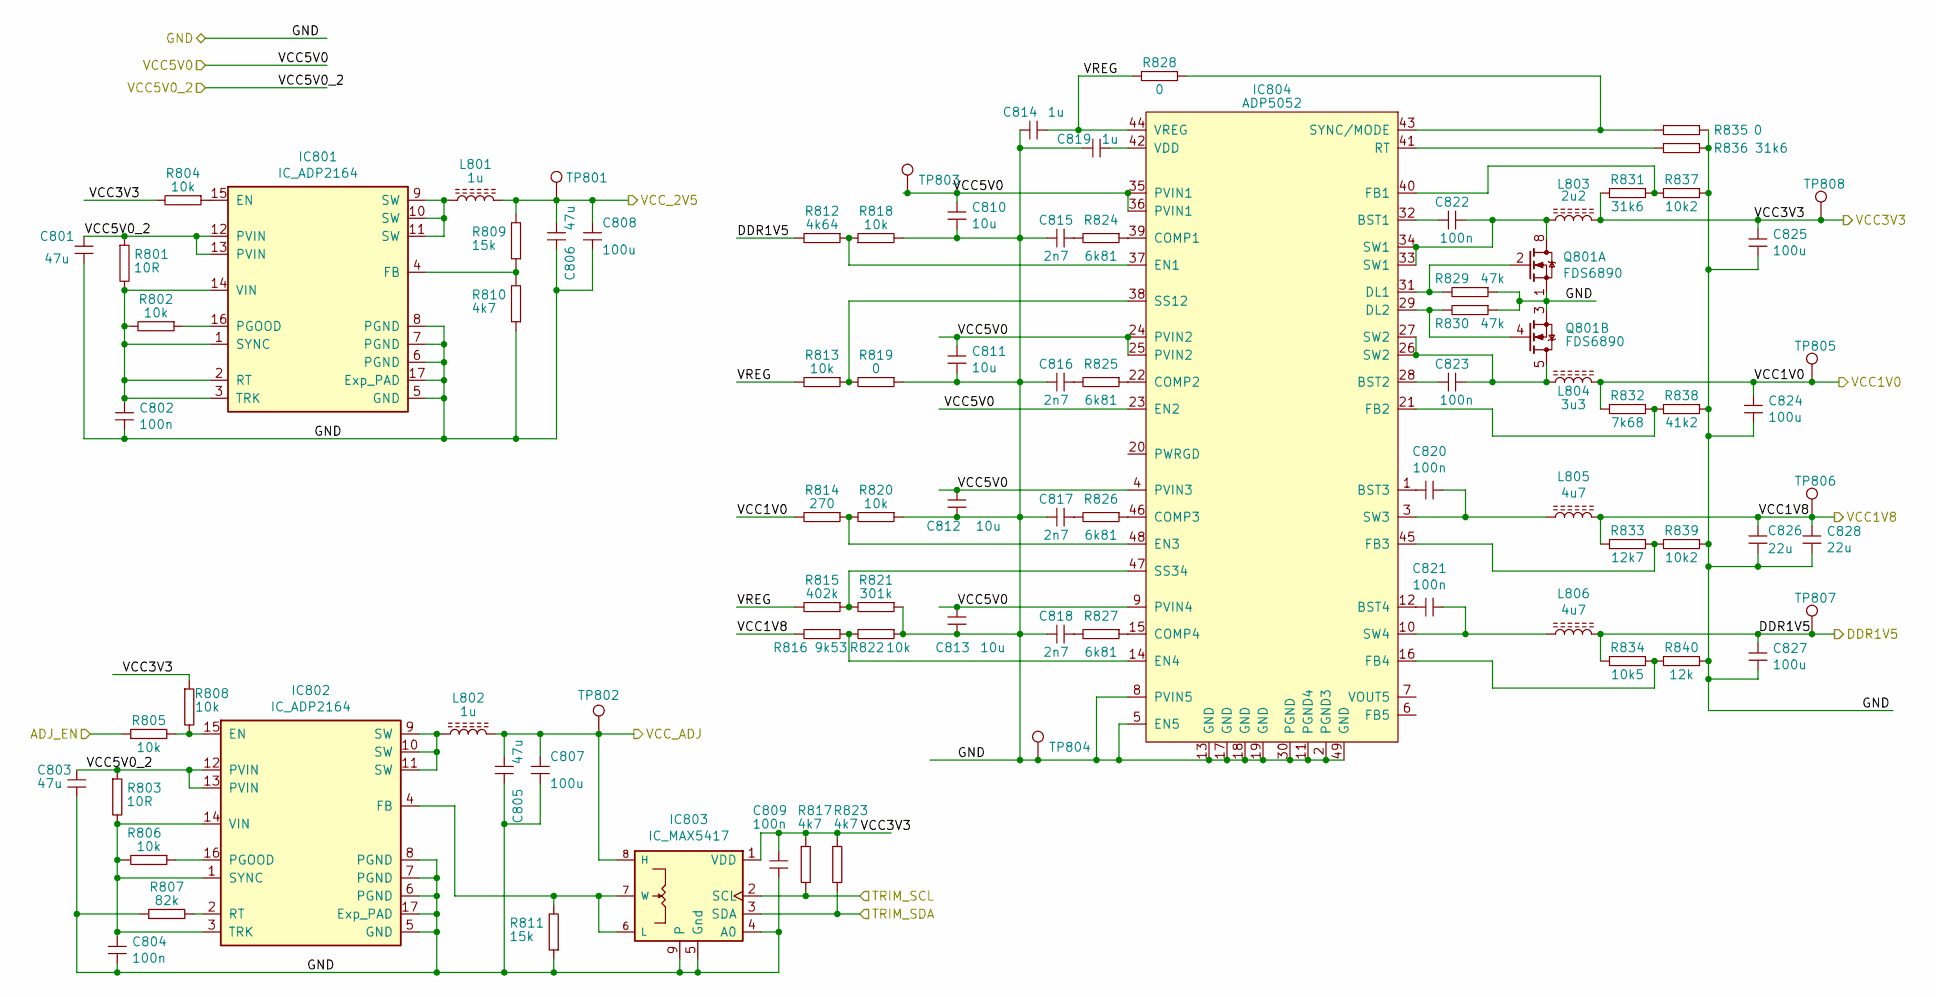
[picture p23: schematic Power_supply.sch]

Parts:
C801, C803, C805, C806: C_47u_0603_6V3; C_0603_1608Metric_Pad1.05x0.95mm_HandSolder
C802, C804, C809, C820, C821, C822, C823: C_100n_0402_16V; C_0402_1005Metric
C807, C808, C824, C825, C827: C_100u_1206_6V3; C_1206_3216Metric_Pad1.42x1.75mm_HandSolder
C810, C811, C812, C813: C_10u_0603_10V; C_0603_1608Metric_Pad1.05x0.95mm_HandSolder
C814, C819: C_1u_0603_10V; C_0603_1608Metric_Pad1.05x0.95mm_HandSolder
C815: C_2n7_0402_10V; C_0402_1005Metric
C816: C_5n6_0402_10V; C_0402_1005Metric
C817, C818: C_1n8_0402_10V; C_0402_1005Metric
C826, C828: C_22u_0603_6V3; C_0603_1608Metric_Pad1.05x0.95mm_HandSolder
IC801, IC802: IC_ADP2164; LFCSP-16-1EP_4x4mm_P0.65mm_EP2.4x2.4mm_ThermalVias
IC803: IC_MAX5417; DFN-8-1EP_3x3mm_P0.65mm_EP1.55x2.4mm
IC804: IC_ADP5052_LFCSP48; LFCSP-48-1EP_7x7mm_P0.5mm_EP4.1x4.1mm_ThermalVias
L801, L802: L_1u_4x4mm; L_4.3x4.3_H3
L803: L_2u2_4x4mm; L_4.3x4.3_H3
L804: L_3u3_4x4mm; L_4.3x4.3_H3
L805, L806: L_4u7_4x4mm; L_4.3x4.3_H3
Q801: Q_FDS6890A_SOIC8; SOIC-8_3.9x4.9mm_P1.27mm
R801, R803: R_10r_0603_5%; R_0603_1608Metric_Pad1.05x0.95mm_HandSolder
R802, R804, R805, R806, R808: R_10k_0402_5%; R_0402_1005Metric
R807: R_82k_0402_5%; R_0402_1005Metric
R809, R811, R827: R_15k_0402_1%; R_0402_1005Metric
R810: R_4k7_0402_1%; R_0402_1005Metric
R812: R_4k64_0402_1%; R_0402_1005Metric
R813, R816: R_9k53_0402_1%; R_0402_1005Metric
R814: R_270r_0402_1%; R_0402_1005Metric
R815: R_402k_0402_1%; R_0402_1005Metric
R817, R823: R_4k7_0402_5%; R_0402_1005Metric
R818, R820, R822: R_10k_0402_1%; R_0402_1005Metric
R819, R828, R835: R_0_0402; R_0402_1005Metric
R821: R_301k_0402_1%; R_0402_1005Metric
R824: R_56k2_0402_1%; R_0402_1005Metric
R825: R_7k15_0402_1%; R_0402_1005Metric
R826: R_9k31_0402_1%; R_0402_1005Metric
R829, R830: R_47k_0402_5%; R_0402_1005Metric
R831, R836: R_31k6_0402_1%; R_0402_1005Metric
R832: R_7k68_0402_1%; R_0402_1005Metric
R833: R_12k7_0402_1%; R_0402_1005Metric
R834: R_10k5_0402_1%; R_0402_1005Metric
R837, R839: R_10k2_0402_1%; R_0402_1005Metric
R838: R_41k2_0402_1%; R_0402_1005Metric
R840: R_12k_0402_1%; R_0402_1005Metric
TP801, TP802, TP803, TP804, TP805, TP806, TP807, TP808: TestPoint; TestPoint_Pad_D1.0mm

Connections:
/Comunication/VBUS: C810.1, C811.1, C812.1, C813.1, IC804.4 (PVIN3), IC804.9 (PVIN4), IC804.23 (EN2), IC804.24 (PVIN2), IC804.25 (PVIN2), IC804.35 (PVIN1), IC804.36 (PVIN1), TP803.1; also elsewhere on the board
/DDR3/DDR1V5: C827.1, L806.2, R812.1, R834.1, TP807.1; also elsewhere on the board
/FPGA_Bank/ADJ_EN: R805.2; also elsewhere on the board
/FPGA_Bank/TRIM_SCL: IC803.2 (SCL), R817.1; also elsewhere on the board
/FPGA_Bank/TRIM_SDA: IC803.3 (SDA), R823.1; also elsewhere on the board
/FPGA_Supply/VCC1V0: C824.1, L804.2, R814.1, R832.1, TP805.1; also elsewhere on the board
/FPGA_Supply/VCC1V8: C826.1, C828.1, L805.2, R816.1, R833.1, TP806.1; also elsewhere on the board
/GND: C801.2, C802.2, C803.2, C804.2, C805.2, C806.2, C807.2, C808.2, C809.2, C810.2, C811.2, C812.2, C813.2, C814.1, C815.1, C816.1, C817.1, C818.1, C819.1, C824.2, C825.2, C826.2, C827.2, C828.2, IC801.5 (GND), IC801.6 (PGND), IC801.7 (PGND), IC801.8 (PGND), IC801.17 (Exp_PAD), IC802.5 (GND), IC802.6 (PGND), IC802.7 (PGND), IC802.8 (PGND), IC802.17 (Exp_PAD), IC803.4 (A0), IC803.5 (Gnd), IC803.9, IC804.2 (PGND3), IC804.5 (EN5), IC804.8 (PVIN5), IC804.11 (PGND4), IC804.13 (GND), IC804.17 (GND), IC804.18 (GND), IC804.19 (GND), IC804.30 (PGND), IC804.49 (GND), Q801.1 (S1), Q801.3 (S1), R807.2, R810.2, R811.2, R818.1, R819.2, R820.2, R821.2, R822.2, R829.2, R830.2, R835.2, R836.2, R837.2, R838.2, R839.2, R840.2, TP804.1; also elsewhere on the board
/IO_Protection/VCCADJ: C805.1, C807.1, IC803.8 (H), L802.2, TP802.1; also elsewhere on the board
/Power_supply/VREG: C814.2, IC804.44 (VREG), R813.1, R815.1, R828.1
/VCC5V0_2: C801.1, C803.1, IC801.12 (PVIN), IC801.13 (PVIN), IC802.12 (PVIN), IC802.13 (PVIN), R801.2, R803.2; also elsewhere on the board
/VCC_2V5: C806.1, C808.1, L801.2, R809.1, TP801.1; also elsewhere on the board
unnamed: C802.1, IC801.1 (SYNC), IC801.2 (RT), IC801.3 (TRK), IC801.14 (VIN), R801.1, R802.1
unnamed: C804.1, IC802.1 (SYNC), IC802.3 (TRK), IC802.14 (VIN), R803.1, R806.1
unnamed: C815.2, R824.1
unnamed: C816.2, R825.1
unnamed: C817.2, R826.1
unnamed: C818.2, R827.1
unnamed: C819.2, IC804.42 (VDD)
unnamed: C820.1, IC804.1 (BST3)
unnamed: C820.2, IC804.3 (SW3), L805.1
unnamed: C821.1, IC804.12 (BST4)
unnamed: C821.2, IC804.10 (SW4), L806.1
unnamed: C822.1, IC804.32 (BST1)
unnamed: C822.2, IC804.33 (SW1), IC804.34 (SW1), L803.1, Q801.7 (D1), Q801.8 (D1)
unnamed: C823.1, IC804.28 (BST2)
unnamed: C823.2, IC804.26 (SW2), IC804.27 (SW2), L804.1, Q801.5 (D1), Q801.6 (D1)
unnamed: IC801.4 (FB), R809.2, R810.1
unnamed: IC801.9 (SW), IC801.10 (SW), IC801.11 (SW), L801.1
unnamed: IC801.15 (EN), R804.2
unnamed: IC801.16 (PGOOD), R802.2
unnamed: IC802.2 (RT), R807.1
unnamed: IC802.4 (FB), IC803.6 (L), IC803.7 (W), R811.1
unnamed: IC802.9 (SW), IC802.10 (SW), IC802.11 (SW), L802.1
unnamed: IC802.15 (EN), R805.1, R808.1
unnamed: IC802.16 (PGOOD), R806.2
unnamed: IC804.14 (EN4), R816.2, R822.1
unnamed: IC804.15 (COMP4), R827.2
unnamed: IC804.16 (FB4), R834.2, R840.1
unnamed: IC804.21 (FB2), R832.2, R838.1
unnamed: IC804.22 (COMP2), R825.2
unnamed: IC804.29 (DL2), Q801.4 (G1), R830.1
unnamed: IC804.31 (DL1), Q801.2 (G1), R829.1
unnamed: IC804.37 (EN1), R812.2, R818.2
unnamed: IC804.38 (SS12), R813.2, R819.1
unnamed: IC804.39 (COMP1), R824.2
unnamed: IC804.40 (FB1), R831.2, R837.1
unnamed: IC804.41 (RT), R836.1
unnamed: IC804.43 (SYNC/MODE), R828.2, R835.1
unnamed: IC804.45 (FB3), R833.2, R839.1
unnamed: IC804.46 (COMP3), R826.2
unnamed: IC804.47 (SS34), R815.2, R821.1
unnamed: IC804.48 (EN3), R814.2, R820.1

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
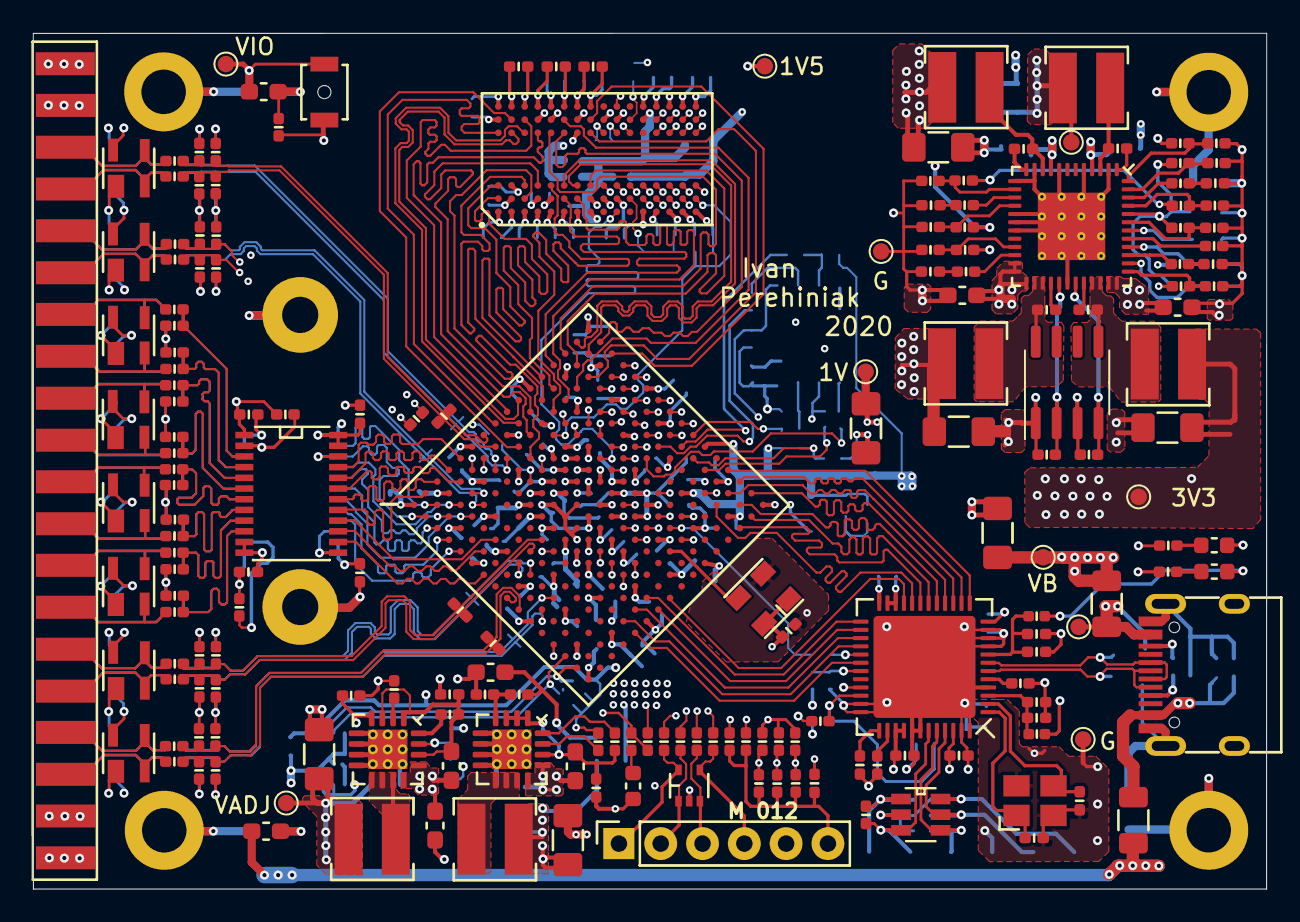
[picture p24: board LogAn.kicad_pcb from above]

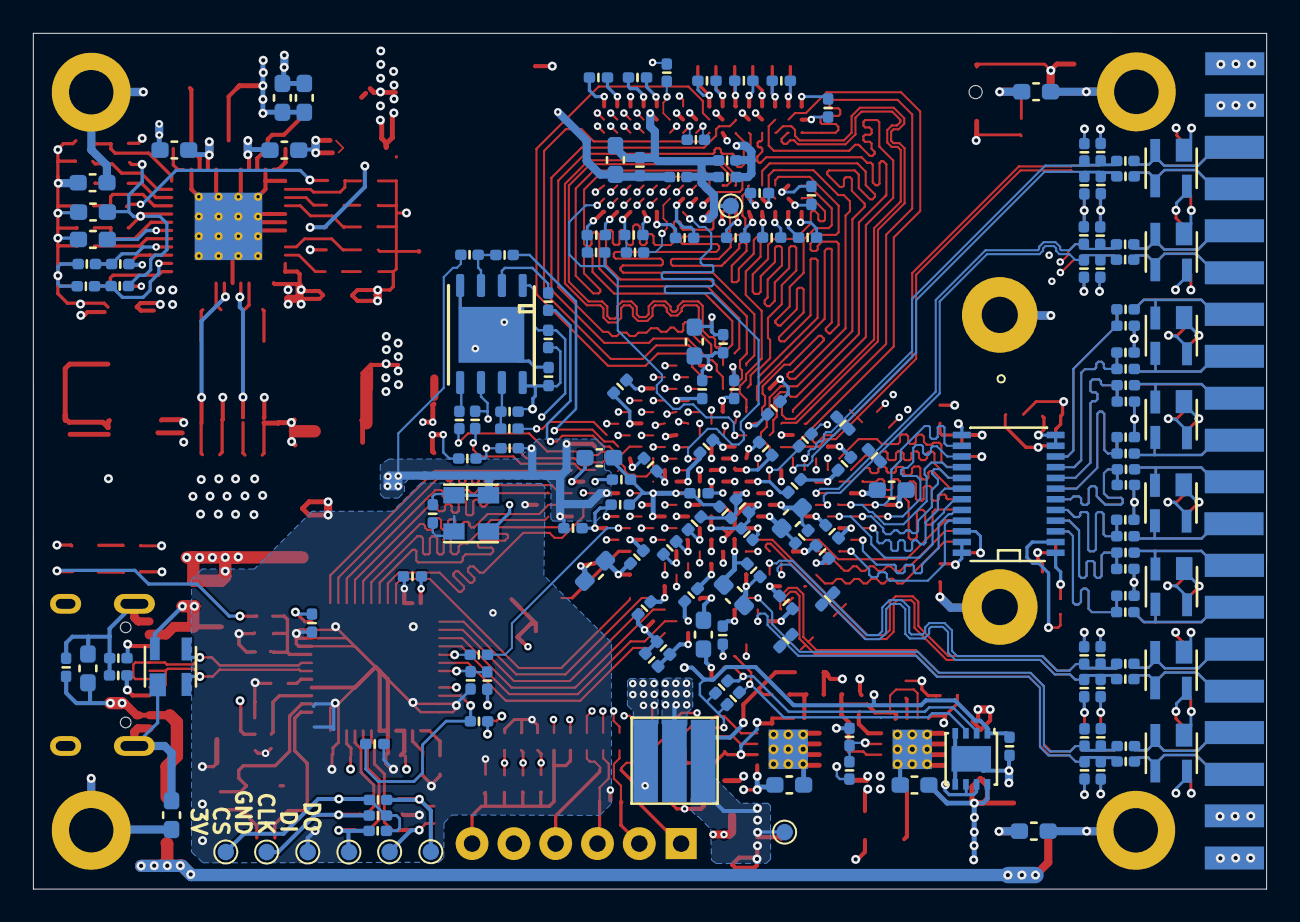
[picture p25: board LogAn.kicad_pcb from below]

Board: 6 copper layers, 74.9 x 52.0 mm, 366 parts (174 on the bottom side), 264 nets.
